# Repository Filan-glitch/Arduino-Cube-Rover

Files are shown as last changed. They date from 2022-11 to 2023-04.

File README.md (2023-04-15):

# Arduino Cube Rover

The Arduino Cube Rover (ACR) is a computer science project made in the university module 'Eingebette Systeme 1' at Hochschule Ruhr West. 
It is about an arduino driving robot controlled by a bluetooth controller with joystick and tilt control. The background is to create a project, that can be reproduced by a school class to get students interested in computer science.

Credits an Arduino Forum System für die Umrechnung der Joystick Rohdaten in Motor Daten. (https://forum.arduino.cc/t/jostick-soll-zwei-motoren-steuern/253709)

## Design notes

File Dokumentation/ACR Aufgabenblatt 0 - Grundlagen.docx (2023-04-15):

Einheit 0: Stromkreis Grundlagen

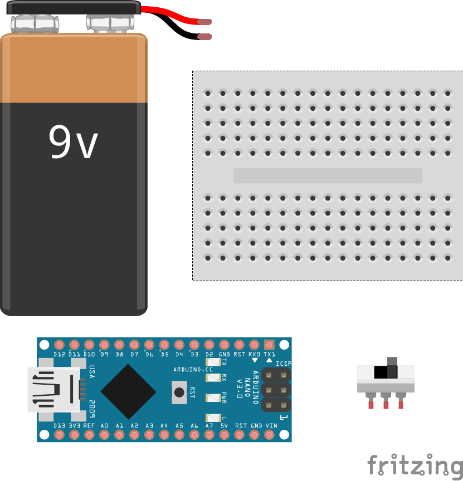
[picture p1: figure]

Materialien

- 1x Arduino Nano
- 1x Breadboard (mittelgroß)
- 1x 9V Batterie
- 1x Batterieblock Kabelaufsatz
- 1x Schalter

Der Arduino wird zum Programmieren immer über ein Kabel an den PC angeschlossen und bekommt dann über den PC den Strom, den es zum Funktionieren braucht. Wenn jedoch ein dynamischer, nicht vom PC abhängiger Roboter und auch Controller gebaut werden soll, muss auf eine kleine mitnehmbare Stromquelle zurückgegriffen werden. In diesem Fall nutzen wir eine 9V Batterie, die direkt an den Arduino angeschlossen werden kann und ihn so mit dem benötigten Strom versorgt.

Abbildung 1 Materialien

Damit der Arduino aber nicht für immer an den Strom angeschlossen ist und einfach die ganze Batterie verbraucht müssen wir eine Steuereinheit verbauen, die den Stromfluss unterbrechen kann und dazu nutzen wir einen Schalter. Dieser kann je nach Auslenkung des Schalters den Stromfluss durchlassen oder blockieren und ist somit perfekt für das An- und Ausschalten des Arduino.

(Falls möglich) Lötvorgang

Wenn man mit verschiedenen Bauteilen arbeitet, kann es häufig dazu kommen, dass man Bauteile nicht mit simplen Jumperkabeln verbinden kann, sondern man selbst Hand anlegen muss und mit dem Lötkolben Bauteile mit Kabeln selbst verlöten muss.

Aufgabe 1

1 | Löte das rote Kabel des Batterieblock Kabelaufsatzes an den mittleren Anschluss des Schalters. Löte ein weiteres rotes Kabel an einen der äußeren Anschlüsse des Schalters.

Das Arbeiten mit Lötkolben ist sehr gefährlich und sollte immer unter höchster Vorsicht durchgeführt werden. Es herrscht Verbrennungsgefahr.

Arduino mit Batterie betreiben

Platziert nun den Arduino Nano mittig auf ein kleines Breadboard, um mit der Verkabelung zu beginnen. Als nächstes müsst ihr den äußeren Anschluss (Pluspol) eures Schalters mit dem VIN-Port des Arduino verbinden, indem ihr das Kabel in einen der Anschlüsse unterhalb des VIN-Ports reinsteckt. Zum Schluss müsst ihr noch das schwarze Kabel vom Batterieblock Kabelaufsatz mit dem GND-Port (Minus Pol) des Arduinos verbinden, dafür steckt ihr das Kabel in ein Loch unterhalb des GND-Ports, der sich neben dem VIN-Port befindet.

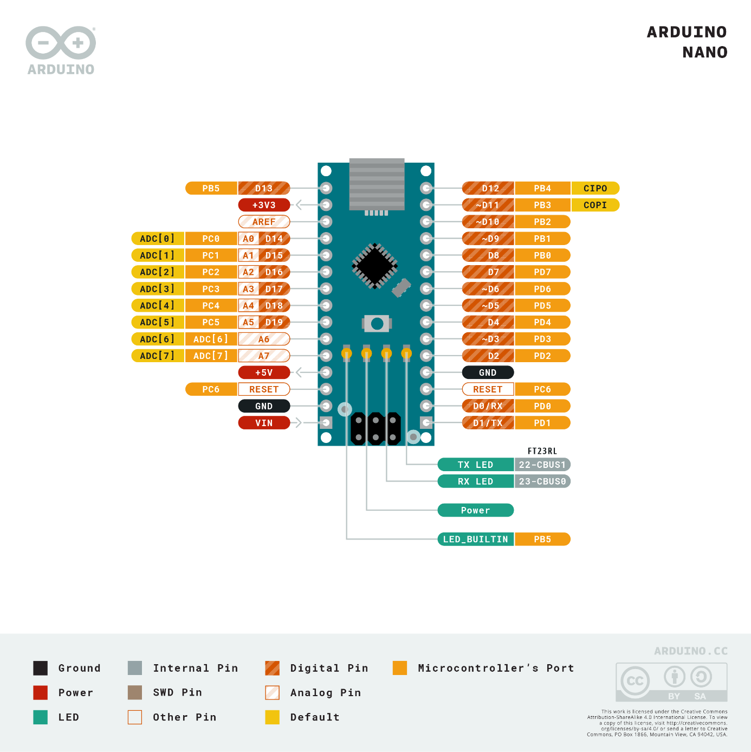
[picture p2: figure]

Abbildung 2 Beschriftung der Anschlüsse des Arduino Nano (https://docs.arduino.cc/hardware/nano)

Aufgabe 2

2 | Baue die beschriebene Schaltung nach, um einen Arduino Nano per Batterie zu betreiben

Bevor der Schalter umgelegt wird, lasse die Schaltung von einer Lehrperson überprüfen. Eine 9V Batterie ist zwar nicht gefährlich aber eine falsche Verkabelung kann schwere Fehler beim Arduino verursachen.

Autoren: Finn Dilan, Felix Neufeld, Jona Tregel Stand: 15.04.2023Seite 1 von 2

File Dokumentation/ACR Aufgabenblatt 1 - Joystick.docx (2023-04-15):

Einheit 1: Joystick

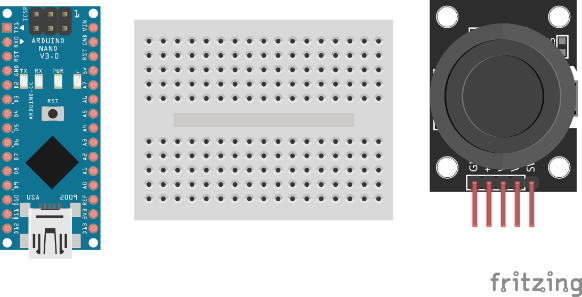
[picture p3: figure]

Materialien

- 1x Arduino Nano mit Verbindungskabel
- 1x mittlere Breadboard
- 1x Joystickmodul
- Jumperkabel weiblich/männlich

Abbildung 1 Materialien

Ein Joystick ist ein Sensor, der die Rotation des Griffs in den zwei Achsen (x-Achse/y-Achse) auslesen kann.

In dieser Einheit wird ein sogenannter analoger Joystick verwendet, welcher die Auslenkung des Griffs mithilfe von zwei Potentiometern ausliest. Ein Potentiometer ist ein elektronisches Bauteil, dass je nach Auslenkung den Widerstand im Stromfluss verändern kann, wird nun dieser Stromfluss ausgelesen kann genau bestimmt werden, wie der Potentiometer ausgerichtet ist. Das vorhandene Joystickmodul hat bereits einen internen Schaltkreis, der den eingehenden und ausgehenden Stromfluss mit den eingebauten Potentiometern verbindet.

Zum Auslesen der Joystick Daten mit dem Arduino müssen wir die Pins des Joystick Moduls nutzen. Wir bilden einen Stromkreis mit den 5V Pins des Arduinos mit dem +5V Pin des Joystickmoduls und dem GND-Pin des Arduinos mit dem GND-Pin des Joystickmoduls. Dadurch fließt nun durch das Joystickmodul Strom. Diesen können wir jedoch noch nicht auslesen, dazu müssen wir die VRx und VRy Pins des Joystickmoduls mit beliebigen Analog Pins des Arduino verbinden. Diese erkennt man an der typischen Kennzeichnung mit einem A und dann einer Zahl, der Pin Nummer, die wir später für die Programmierung brauchen, um auch die richtigen Daten auszulesen.

Joystick anschließen

Der Arduino wird auf dem Breadboard angebracht, um das Verbinden mit Strom und dem Joystick zu vereinfachen.

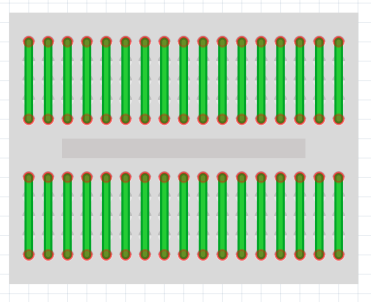
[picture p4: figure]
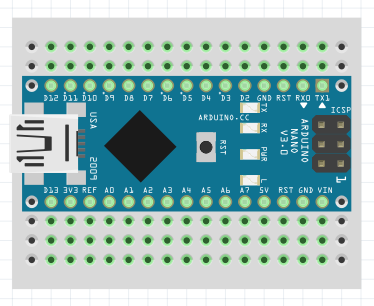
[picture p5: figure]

Abbildung 2 Verbindungen auf dem Breadboard. Jede durchgezogene Linie steht für eine Verbindung der darunter liegenden Anschlüssen.

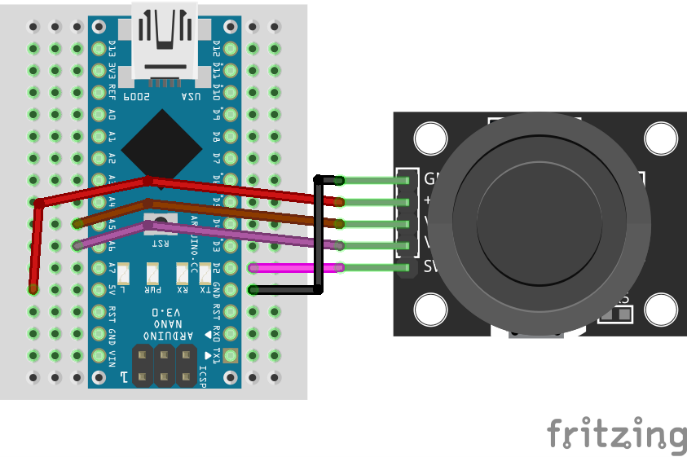
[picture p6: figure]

Die Schaltung des Joysticks ist sehr simpel. Da der Joystick als Modul ein eigenes Leiterbahnensystem besitzt muss nur noch die Anschlüsse des Joysticks mit dem Arduino verbunden werden. Dazu nutzen wir die Informationen aus der Einführung, welche Pins das Modul besitzt und wie sie an den Arduino anzuschließen sind.

Abbildung 3 Schaltbild zum Anschluss eines Joystick Moduls an den Arduino Nano

Wenn nun alles an Ort und Stelle ist wollen wir natürlich auch die Daten des Joysticks auslesen. Der Joystick hat drei Daten-Pins: die horizontale Achse (analog), die vertikale Achse (analog) und den Taster (digital). Digitale Pins müssen zu Beginn eines Skripts immer als Eingang oder Ausgang definiert werden. Dazu nutzt man den Befehl pinMode.

Analoge Pins brauchen diese Definition nicht, weshalb wir direkt mit dem Auslesen der Daten anfangen können. Zum Auslesen benutzen wir den Befehl analogRead.

analogRead(pin);
Beschreibung | Mit diesem Befehl wird der aktuelle Wert an dem angegebenen Pin ausgelesen.
Parameter | pin: Nummer des Pins, dessen Wert ausgelesen werden soll
Rückgabewert | Der ausgelesene Wert als Ganzzahl (int)

Nun könnt ihr die Werte des Joysticks auslesen, wisst jedoch noch nicht, wie man die Werte menschenlesbar anzeigt. Dafür gibt es den seriellen Monitor auf dem man Texte, Werte oder andere nützliche Sachen anzeigen lassen kann. Der Befehl zum Anzeigen von Dingen auf dem seriellen Monitor lautet Serial.print(). Damit die serielle Kommunikation genutzt werden kann, muss in der setup() noch der Befehl Serial.begin() genutzt werden.

Serial.begin(speed);
Beschreibung | Dieser Befehl wird genutzt, um die serielle Kommunikation mit der angegebenen Geschwindigkeit zu starten. Die Geschwindigkeit ist wichtig, damit
Parameter | Speed: Die Geschwindigkeit der Kommunikation (Standard ist 9600, später wird auch 38400 benötigt)
Rückgabewert | void

Serial.print(data); / Serial.println(data);
Beschreibung | Dieser Befehl wird genutzt, um nützliche Informationen auf dem seriellen Monitor anzeigen zu lassen. Serial.println() ist eine Erweiterung von Serial.print(), die nach der angezeigten Information automatisch ein Zeilenumbruch macht.
Parameter | data: Informationen, die auf dem seriellen Monitor angezeigt werden sollen, das kann ein Text sein, eine Variable oder auch Arrays.
Rückgabewert | Gibt die Anzahl an Zeichen zurück, die tatsächlich geschrieben wurden, falls es zu Problemen mit dem Schreiben kommen sollte.

Aufgabe 1

1a | Schließt den Joystick richtig an den Arduino an und erstellt einen kleinen Sketch, mit dem ihr mit Hilfe von Serial.println() die Werte in dem Debug Fenster ausgebt.
1b | Was sind die jeweiligen Wertepaare in den äußersten Ecken des Joysticks? Jeweils in der Form (x-Achse, y-Achse).
| Oben Links
| Oben Rechts
| Unten Links
| Unten Rechts

Mit den Daten arbeiten

Infotext (Große Programmieraufgabe, die map Funktion einführen zum mappen von einem Zahlenbereich auf einen anderen und dann mit mit If-Abfragen, interne LED auf Pin 13 erklären und aufblicken lassen, wenn das produkt der beiden Achsen werte kleiner einem bestimmten Wert ist oder so).

Das Anschließen und Einlesen der Werte haben funktioniert? Dann fangen wir nun an die eingelesenen Werte mal etwas mehr zu benutzen. Die Wertespanne des Joysticks ist, wie sicherlich schon herausgefunden, beschränkt auf Werte von 0 bis 1023. Manchmal ist es jedoch durchaus hilfreich andere Wertespannen zu haben, weil es sich damit leichter arbeiten lässt. Deshalb gibt es den map Befehl.

Aufgabe 2

map(value, fromLow, fromHigh, toLow, toHigh);
Beschreibung | Dieser Befehl arrangiert die Werte so um, dass sie von dem alten Wertebereich nun vollständig in den neuen Wertebereich passen. Dieser Befehl arbeitet nur mit ganzen Zahlen, daher die Grenzen nur als ganze Zahlen angeben.
Parameter | value: die Variable, dessen Werte neu arrangiert werden sollen fromLow: die untere Grenze des alten Wertebereichs fromHigh: die obere Grenze des alten Wertebereichs toLow: die untere Grenze des neuen Wertebereichs toHigh: die obere Grenze des neuen Wertebereichs
Rückgabewert | Die neu arrangierte Ganzzahl mit der dann weitergearbeitet werden kann.

2 | Code schreiben - Lies die x-Werte und y-Werte aus dem Joystick aus und speicher diese in jeweils einer Variable ab - Mappe die Werte, die ursprünglich von 0 bis 1023 gingen auf den neuen Wertebereich von -256 bis 255 - Erstelle eine Bedingung, dass im seriellen Monitor „True“ ausgegeben wird, wenn der x-Wert addiert mit dem y-Wert größer als oder gleich 0 ist. Wenn kleiner, soll „False“ ausgegeben werden.

Den Taster auslesen

Nun beschäftigen wir uns mit dem Taster des Joysticks, der erkennt, ob der Joystick gedrückt wurde. Dazu gibt es den digitalen SW-Pin. Bei digitalen Bauteilen/Anschlüssen müssen wir den Arduino darüber informieren, ob über diesen Pin Daten empfangen oder wir Daten ausgeben wollen. Für diese Definition gibt es den pinMode Befehl.

pinMode(pin, mode);
Beschreibung | Der Befehl legt fest, ob ein bestimmter digitaler Pin als Eingabe oder Ausgabe benutzt werden soll. Wird in void setup() eingesetzt.
Parameter | pin: Nummer des Pins, dessen Modus gesetzt werden soll mode: INPUT (Eingabe) oder OUTPUT (Ausgabe), es gibt auch noch den Spezial Modus INPUT_PULLUP (Eingabe), den wir für den Joystick Taster benötigen werden.
Rückgabewert | void

Wenn wir nun auslesen wollen, ob der Joystick gedrückt wurde, müssen wir den Befehl digitalRead nutzen.

digitalRead(pin);
Beschreibung | Mit diesem Befehl wird an dem angegebenen digitalen Pin ausgelesen, ob der Wert des Pins HIGH oder LOW ist. Der Joystick-Taster gibt immer einen LOW-Wert zurück und wenn gedrückt wechselt er für die Zeit des Drückens auf HIGH
Parameter | pin: Nummer des Pins, dessen Wert ausgelesen werden soll
Rückgabewert | HIGH oder LOW

Das Problem nun ist, dass wir damit nur abfragen können, ob der Taster aktuell gedrückt wird. Wenn gespeichert werden soll, dass der Taster gedrückt wurde, wird es etwas komplizierter. Es muss gespeichert werden, ob der Taster aktuell gedrückt ist (kann auch in der Abfrage direkt ausgelesen werden), es muss gespeichert werden, ob der Taster bei der letzten Abfrage gedrückt war (bool) und es muss einen Modus geben, der hin und her springt, wenn der Taster einmal vollständig gedrückt und losgelassen wurde (enum).

Aufgabe 3

3

Code erweitern

- Lege eine bool Variable an, die speichert, ob der Taster beim letzten Mal gedrückt war.
- Lege einen enum an, der zwei verschiedene Modi definiert.
- Schreibe eine Funktion, die in den jeweils anderen Modus wechselt, wenn die bool Variable auf true ist und der aktuelle Taster LOW ausgelesen wird (nach dem Wechseln nicht vergessen die bool Variable auf false zu setzen). Am Ende der Funktion soll die bool Variable nochmal auf den aktuellen Taster-Wert gesetzt werden.
- Zu guter Letzt soll die Bedingung aus der Aufgabe 2 so geändert werden, dass wenn der erste Modus aktiviert ist, soll weiterhin „True“ ausgegeben werden, wenn xAchse PLUS yAchse größer oder gleich 0 ist, aber wenn der zweite Modus aktiviert ist, soll „True“ ausgegeben werden, wenn xAchse MAL yAchse größer oder gleich 0 ist.

Autoren: Finn Dilan, Felix Neufeld, Jona Tregel Stand: 15.04.2023Seite 1 von 2

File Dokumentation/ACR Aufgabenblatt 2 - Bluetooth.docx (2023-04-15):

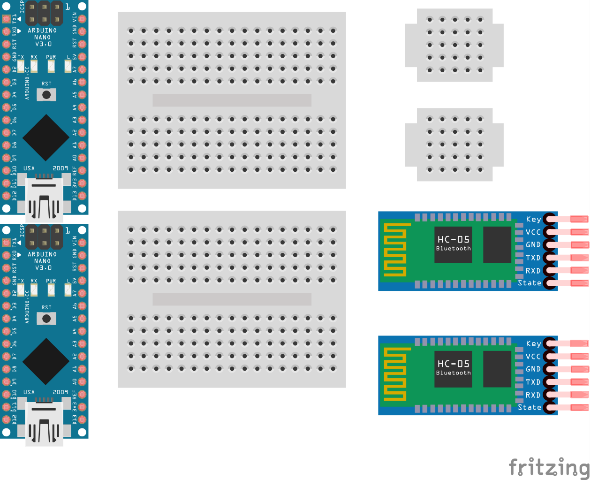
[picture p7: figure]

Einheit 2: Bluetooth Verbindung

Materialien

- 2x Arduino Nano (+Verbindungskabel)
- 2x Bluetooth Modul HC-05
- 2x Breadboards (mittelgroß)
- 2x Breadboards (klein)
- Jumperkabel männlich/männlich und weiblich/männlich

Abbildung 1 Materialien

Im Alltag kommt man ständig mit Bluetooth in Verbindung, aber wie ist das eigentlich technisch umgesetzt? Die grundlegende Kommunikation wird über Bluetooth-Module umgesetzt, Kleine in sich funktionierende Chips, die das Suchen, Verbinden und die Übertragen zu großen Teilen übernehmen und automatisieren.

Es gibt zwei verschiedene Modul Typen, die verschiedene Stellungen übernehmen, denn bei Bluetooth Verbindungen gibt es immer einen Master, der die Verbindung einleitet und die Kommunikation übernimmt und einen Slave, der nur „ausgenutzt“ wird und die Verbindung und Daten annehmen muss. Das HC-06 ist ein reines Slave-Modul, dass keine eigenen Verbindungen aufbauen kann, sondern nur bspw. von einem Handy Daten empfangen kann. Das HC-05 Modul hingegen kann sowohl als Master- als auch Slave-Modul genutzt werden und ist deshalb perfekt für eine Kommunikation in beide Richtungen.

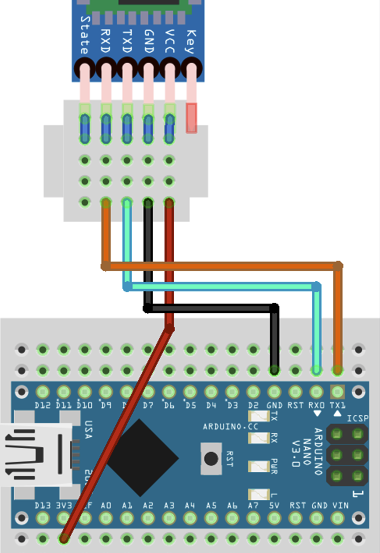
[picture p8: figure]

Das HC-05 Modul besitzt sechs verschiedene Pins: Der GND und VCC-Pin sind für die Stromversorgung zuständig, dabei wird der GND-Pin mit dem GND-Pin des Arduinos verbunden und der VCC-Pin mit dem 3V Pin des Arduino. Der State Pin kann an einen beliebigen Digital Pin angeschlossen werden und gibt ein High/Low-Signal, je nachdem ob aktuell eine aktive Verbindung existiert oder nicht. Der RXD- und TXD-Pin sind die Datenpins des Moduls und werden vertauscht mit den RX0- und TX1- Pin des Arduinos verbunden. Der EN-Pin ist ein Konfigurations-Pin und standardmäßig nicht verbunden.

Bluetooth Modul anschließen

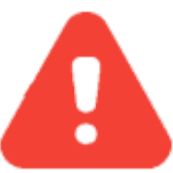
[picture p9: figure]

Der Arduino wird standardmäßig auf dem mittelgroßen Breadboard angebracht. Das HC-05 Modul wird auf dem kleinen Breadboard angebracht, damit das passt, muss man den EN-Pin etwas nach oben biegen.

Unbedingt darauf achten, dass das HC-05 Modul mit dem 3V Pin des Arduinos verbunden wird. Auf keinen Fall an den 5V Pin anschließen. Das kann zu schweren Schäden an dem HC-05 Modul führen.

Aufgabe 1

1 | Befestige den Arduino und das HC-05 Modul auf ihren jeweiligen Breadboards und verbinde die Pins korrekt.

Konfiguration

Das Ziel ist es zwei Arduinos über Bluetooth miteinander kommunizieren zu lassen. Dazu müssen die Bluetooth-Module so konfiguriert werden, dass sie sich finden und automatisch koppeln können. Dabei sollen die Module auch nicht von anderen Geräten gefunden werden können. Um ein HC-05 Modul konfigurieren zu können müssen wir das Modul in den Konfigurationsmodus bringen, dazu verbinden wir den EN-Pin mit dem Arduino an Digital-Pin 3, dann können wir mit dem Skript später den Arduino in den AT-Modus bringen. Dieser Modus lässt sich erkennen daran, dass die LED des HC-05 Moduls anders blinkt als zuvor.

Die Kommunikation des HC-05 Moduls funktioniert über die gleichen Kanäle wie die serielle Kommunikation, daher kann es zu gegenseitigen Störungen kommen. Um das zu verhindern kann man einen virtuellen RX/TX Kanal erstellen. Dazu nutzen wir die Bibliothek „SoftwareSerial“ und können dann mit dem einen neuen seriellen Kanal als Variable definieren, dabei sind dann die beiden angegebenen Pins, die neuen virtuellen RX und TX-Pins. Verbinde also den RX-Pin des HC-05 Moduls jetzt mit Digital-Pin 5 des Arduinos und den TX-Pin des HC-05 Moduls mit dem Digital-Pin 4 des Arduinos. Eine beispielhafte Anwendung siehst du im Skript, dass wir für den Konfigurationsmodus brauchen.

Wenn das Modul sich im AT-Modus befindet, solltest du im seriellen Monitor den Text „Enter AT commands:“ lesen können und wenn du „AT“ eingibst und sendest, sollte ein „OK“ zurückkommen, dann hat alles korrekt funktioniert. Wenn es zu einem Fehler gekommen ist, versuch es noch einmal oder hole dir Hilfe bei deinem Lehrer.

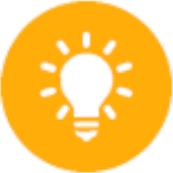
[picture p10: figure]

Es gibt nun ein paar Einstellungen, die im AT-Modus eingestellt werden müssen. Zuerst interessiert uns die Adresse des Moduls, diese kriegen wir mit dem Befehl „AT+ADDR?“, als Antwort sollte dann die Adresse des Moduls erscheinen. Notier dir diese. Danach wollen wir die Rolle des Moduls einstellen. Wir haben zwei Module, eines davon soll als Master eingestellt werden, das andere als Slave. Mit dem Befehl „AT+ROLE=“ kann man die Rolle einstellen, eine 0 an das Ende gehangen ändert die Rolle des Moduls zu einem Slave-Modul, eine 1 an das Ende gehangen ändert die Rolle des Moduls zu einem Master-Modul. Mit dem Befehl „AT+CMODE=0“ können wir dem Modul befehlen, sich mit niemanden zu verbinden, außer der verbundenen Adresse, die wir im nächsten Schritt angeben. Im besten Fall weißt du jetzt die Adressen von beiden Modulen, denn im nächsten Schritt müssen wir beiden Modulen jeweils die Adresse des anderen übergeben. Mit dem Befehl „AT+BIND=“ befehlen wir dem Modul, mit welcher Adresse es sich verbinden soll. Häng einfach die Adresse des anderen Moduls an das Ende des Befehls.

#include <SoftwareSerial.h>//Bibliothek für virtuellen Kanal

SoftwareSerial BTSerial(4, 5); //name(RX-Pin, TX-Pin)

void setup()

{

pinMode(3, OUTPUT);

digitalWrite(3, HIGH);

Serial.begin(38400);

Serial.println("Enter AT commands:");

BTSerial.begin(38400);

}

void loop()

{

if (BTSerial.available()) Serial.write(BTSerial.read());

if (Serial.available()) BTSerial.write(Serial.read());

}

Wenn es beim Hochladen zu Problemen kommt, kann das an dem HC-05 Modul liegt, dass verursacht manchmal Probleme beim Hochladen. Einfach den RX/TX Pin für die Dauer des Hochladen herausziehen, dann sollte alles wieder funktionieren.

Aufgabe 2

2a | Verbinde den EN-Pin und den RX/TX-Pin des HC-05 Moduls an die korrekten Pins des Arduinos.
2b | Lade den oben angegebenen Code auf den Arduino hoch.
2c | Konfiguriere beide deiner HC-05 Module - AT+ADDR? - AT+ROLE=0/1 - AT+CMODE=0 - AT+BIND=ADDR

Verbindung und Kommunikation

Wenn beide HC-05 Module korrekt konfiguriert wurden sollten diese sich nun automatisch verbinden, wenn beide eingeschaltet und kopplungsbereit sind.

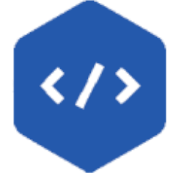
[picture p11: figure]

Wie bereits im Text zu Aufgabe 2 beschrieben, nutzen wir bei der Verwendung von HC-05 Modulen häufig virtuelle serielle Kommunikation. Diese kann effektiv die gleichen Befehle durchführen wie die echte serielle Verbindung (BTSerial.print()/BTSerial.println()). Bei der Kommunikation von rohen Daten über die Bluetooth Verbindung nutzt man eher den Befehl BTSerial.write(). Um die serielle Kommunikation zu nutzen muss sie wieder gestartet werden, diesmal beide Serial.begin() und BTSerial.begin() beide mit der Geschwindigkeit 38400.

BTSerial.write(array, array_length);
Beschreibung | Dieser Befehl wird genutzt, um Rohdaten, die nicht von dem Arduino verändert werden sollen, über die Bluetooth-Verbindung zu verschicken.
Parameter | array: Informationen, die über die Bluetooth-Verbindung geschickt werden sollen, gespeichert in einem Array. Es können nur positive Zahlen geschickt werden, wollen also negative Zahlen übertragen werden, müssen die vorher in positive Zahlen umgewandelt werden und nach der Übertragung wieder zurück. array_length: Die Anzahl an Elementen, die in dem Array enthalten sind
Rückgabewert | Gibt die Anzahl an Zeichen zurück, die tatsächlich geschrieben wurden, falls es zu Problemen mit dem Schreiben kommen sollte.

Der Slave, der die Daten bekommt, will in der loop() nun wissen, ob Daten über die Bluetooth Verbindung angekommen sind und nutzt dafür den BTSerial.available() Befehl.

Für das eigentliche Auslesen der Rohdaten geschieht dann über den BTSerial.readBytes() Befehl.

BTSerial.readBytes(array, array_length);
Beschreibung | Dieser Befehl wird genutzt, um angekommene Rohdaten aus dem Bluetooth-Modul auszulesen.
Parameter | array: Das Array, in das die Daten reingeschrieben werden sollen array_length: Die Anzahl der Elemente die gelesen werden sollen
Rückgabewert | Gibt die Anzahl an Bytes zurück, die tatsächlich gelesen wurden.

BTSerial.available();
Beschreibung | Dieser Befehl wird genutzt, um abzufragen, ob Bluetooth Daten verfügbar sind zu lesen.
Parameter | void
Rückgabewert | Gibt einen bool zurück, true, wenn Daten verfügbar sind, false, wenn nicht

Aufgabe 3

3a | Verbinde beide Arduinos mit ihrem jeweiligen HC-05 Modul.
3b | Code schreiben - Master Sketch - Erstelle einen virtuellen seriellen Kanal - Schicke einmal ein char Array mit den Werten 1, 2 und 3 - Schicke einmal ein char Array mit den Werten -1, 0 und 1 - Gib jeweils alle geschickten Werte auch auf dem seriellen Monitor aus - Slave Sketch - Erstelle einen virtuellen seriellen Kanal - Teste, ob Daten über die Bluetooth-Verbindung angekommen sind - Wenn Daten vorhanden sind, lies sie in ein vorher angelegtes Array ein - Gib die angekommenen Daten auf dem seriellen Monitor aus

Aktuellen Status auslesen

Der letzte Pin, den wir von dem HC-05 Modul bisher noch nicht verwendet haben ist der State-Pin. Dieser Pin kann bei Bluetooth-Verbindungen, die auf eine aktive Verbindung angewiesen sind, ganz hilfreich sein, um zu erkennen, ob die Verbindung noch besteht. Wenn an einen Digital-Pin angeschlossen gibt er dauerthaft HIGH/LOW-Werte, je nach Verbindungsstatus.

Aufgabe 4

4a | Verbinde den State-Pin mit einem Digital-Pin des Arduinos.
4b | Code schreiben - Beide Arduinos sollen auf dem seriellen Monitor „True“ ausgeben, solange eine aktive Bluetooth-Verbindung besteht - Es soll „False“ ausgegeben werden, wenn die Verbindung nicht mehr besteht

Das Modul braucht immer zwischen 3-5 Sekunden bis der State-Pin aktualisiert wird, also bei kleinen Verzögerungen nicht verwirrt sein.

Autoren: Finn Dilan, Felix Neufeld, Jona Tregel Stand: 15.04.2023Seite 1 von 2

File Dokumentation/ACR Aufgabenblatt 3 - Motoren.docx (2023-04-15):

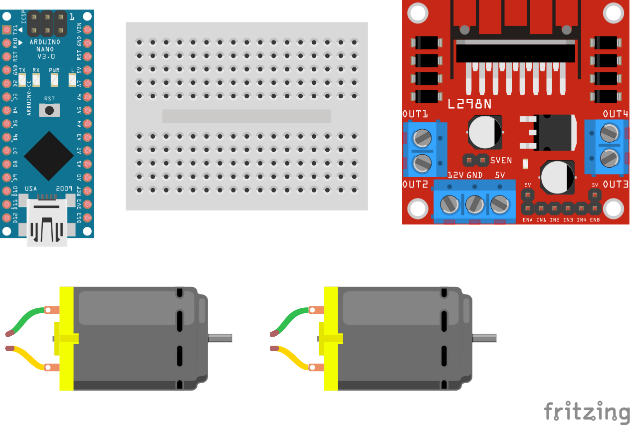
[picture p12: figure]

Einheit 3: Motoren

Materialien

- 1x Arduino Nano
- 2x Gleichstrommotor
- 1x H-Brücke L298N
- 1x Breadboard (mittelgroß)
- Jumperkabel männlich/männlich

Abbildung 1 Materialien

Ein Gleichstrommotor, dient zum Antrieb von vielen verschiedenen Geräten und Modulen. In unserem Fall wird er simpel das Rad antreiben, welches den Roboter fortbewegt. Der Motor besitzt 2 Anschlüsse (+ und –), die für die Stromzufuhr zuständig sind.

Der Motor wird zur korrekten Anwendung an eine sogenannte H-Brücke angeschlossen, diese reguliert durch die vier Schalter (S1, S2, S3, S4) die Stromrichtung und damit die Drehrichtung und auch die Geschwindigkeit des Motors. Des Weiteren besitzt die H-Brücke eine höhere Strombelastbarkeit als der Arduino und ist somit Antriebsstärker, also perfekt für unseren Anwendungszweck.

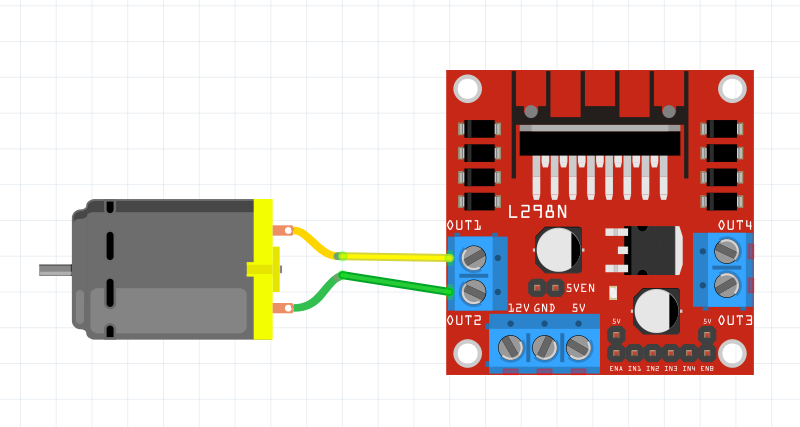
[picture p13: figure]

Die Kabel des Motors, werden an die gleich gekennzeichneten Pins der H-Brücke angeschlossen.

Abbildung 2 Verkabelung Motor/H-Brücke

Die H-Brücke

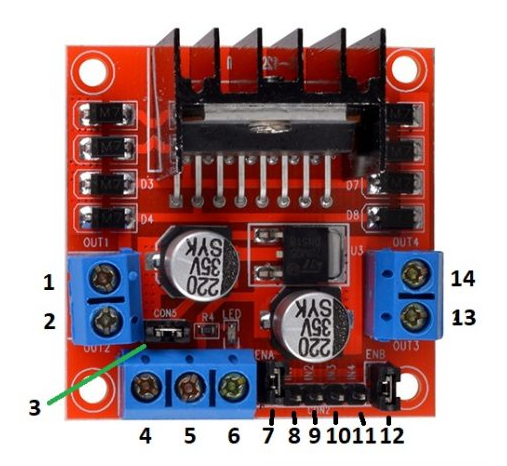
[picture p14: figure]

Damit die Motoren funktionstüchtig an die H-Brücke angeschlossen werden können, muss diese natürlich mit dem Arduino Nano verknüpft sein.

Für eine korrekte Funktionsweise werden im Folgenden die Pins und ihre Funktion angegeben.

Abbildung 3 Pin-out H-Brücke

Nützliche Pins der H-Brücke

Pin | Funktion
1 | Anschluss für den Gleichstrommotor 1 „+“
2 | Anschluss für den Gleichstrommotor 1 „-“
3 | Jumper
4 | Eingang für die Spannungsversorgung der H-Brücke (max. 35V Gleichstrom)
5 | Eingang für den GND
6 | 5V Ausgang, z.B. für die Stromversorgung des Mikrocontrollers
7 | Pin, über den der Gleichstrommotor 1 angesteuert wird. Falls dieser Pin an einem PWM-Pin des Mikrocontrollers angeschlossen wurde, kann die Motorengeschwindigkeit ebenfalls genau bestimmt werden
8 | Pin IN1 – Steuert Gleichstrommotor 1
9 | Pin IN2 – Steuert Gleichstrommotor 1
10 | Pin IN3 – Steuert Gleichstrommotor 2
11 | Pin IN4 – Steuert Gleichstrommotor 2
12 | Pin, über den der Gleichstrommotor 2 angesteuert wird. Falls dieser Pin an einem PWM-Pin des Mikrocontrollers angeschlossen wurde, kann die Motorengeschwindigkeit ebenfalls genau bestimmt werden
13 | Anschluss für den Gleichstrommotor 2 „+“
14 | Anschluss für den Gleichstrommotor 2 „-“

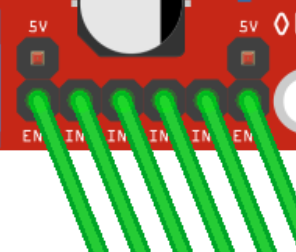
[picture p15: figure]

Nutze zuerst 6 Kabel und stecke jeweils einen Kopf in die Pins 7-12 der H-Brücke (siehe „Die H-Brücke“).

Die anderen Enden der Kabel werden, ohne sich zu überkreuzen an die Pins des Arduinos D11-D6 gesteckt.

Abbildung 4 Verkabelung Digital Anschlüsse

Aufgabe 1

Die Motoren sollen beim Testen der Funktionen die Rotationsrichtung, sowie die Geschwindigkeit ändern können! Pins, beachten.

1 | Platziere den Arduino wie bekannt auf dem Breadboard und schließe dann die H-Brücke an den Arduino an. Beachte die Pins 7 und 12 an PWM-Pins des Arduinos anzuschließen.

Motoren an die H-Brücke anschließen

Wir nehmen die Pins 1,2 und 13,14 für die Kabel der Motoren.

Beachte,

dass die mit „+“ und „-“ gekennzeichneten Pins der H-Brücke mit den gleichnamigen Kabeln der Motoren verbunden werden und der „+“ Pin auf der einen Seite oben und der „-“Pin auf der anderen oben ist!

Da die die Motoren eine höhere Spannung benötigen als der Arduino geben kann, benötigt die H-Brücke eine zusätzliche Spannungsquelle. Also schließen wir an die vorgesehenen Pins (Eingang, GND) der H-Brücke eine 9V Batterie an.

Aufgabe 2

2 | Verbinde die Motoren mit den richtigen Pins der H-Brücke. Schließe eine 9V Batterie an die H-Brücke als zusätzliche Spannungsquelle an.

Motoren initialisieren

Die Motoren werden über die zwischengeschaltete H-Brücke angesteuert und besitzen dafür drei Anschlüsse. Den Geschwindigkeits-Anschluss und jeweils zwei Richtungs-Anschlüsse. Da das Merken der Pin-Nummern und ständige schreiben der Zahlen schnell zu Fehlern kommen kann, speichern wir die Pin-Nummern von Modulen ab sofort als Variablen ab. Der Effizienz wegen werden die Variablen als const deklariert. Der Datentyp ist ein int.

Da bei den Motoren sämtliche Anschlüsse digital sind, müssen wir alle sechs Pins in der setup() als OUTPUT definieren.

Aufgabe 3

3 | Code schreiben - Erstelle konstante Variablen, die die Pin-Nummern abspeichern. Überlege dir eine gute Bezeichnung, damit der Code einfacher zu lesen ist. - Definiere alle Anschlüsse in der setup() als OUTPUTS

Motoren ansteuern

Damit die Motoren angesteuert werden können, müssen wir sowohl die Geschwindigkeit als auch die Richtung angeben. Die Geschwindigkeit geben wir an, indem wir dem Geschwindigkeits-Pin mit dem neuen Befehl analogWrite() eine Geschwindigkeit vorgeben, dabei ist 0 Stillstand und 255 Vollgas. Die Richtung bestimmen wir über die zwei Richtungs-Pins. Diese müssen auf gegensätzliche HIGH/LOW Werte gesetzt werden. Also Richtungs-Pin 1 wird auf HIGH gesetzt und Richtungs-Pin 2 auf LOW ist vorwärts, während andersherum rückwärtsfahren bedeutet. Wenn beide Pins auf LOW gesetzt werden, ist das der Stillstand Modus und der Motor hört auf sich zu drehen. Dazu nutzen wir den neuen Befehl digitalWrite(). Ein dritter nützlicher Befehl ist der Warte-Befehl delay(). Damit kann man das Programm für kurze Zeit pausieren

delay(int);
Beschreibung | Mit diesem Befehl kann man die Ausführung des nachfolgenden Codes für die angegebene Zeit pausieren. Gesendete Signale bleiben aktiv.
Parameter | int: Die Anzahl an Millisekunden, die das Programm pausiert werden soll (1000ms = 1s)

digitalWrite(pin, HIGH/LOW);
Beschreibung | Mit diesem Befehl kann man auf dem angegebenen Pin digitale Signale (HIGH oder LOW) senden.
Parameter | pin: Nummer des Pins, auf der das Signal gesendet werden soll HIGH/LOW: die Auswahl des Signals, das gesendet werden soll, entweder ein HIGH oder ein LOW-Signal.
Rückgabewert | void

analogWrite(pin, int);
Beschreibung | Mit diesem Befehl kann man auf dem angegebenen Pin analoge Signale (0-255) senden.
Parameter | pin: Nummer des Pins, auf der das Signal gesendet werden soll int: Die Ganzzahl, die als Signal gesendet werden soll, bei Nutzung von Variablen, muss der Datentyp int sein.
Rückgabewert | void

Aufgabe 4

4 | Code erweitern - Definiere eine enum, die die Richtung abspeichern kann (vorwärts, rückwärts oder stillstand). - Erstelle zwei Hilfsfunktionen, eine jeweils für jeden Motor, die eine Richtung übergeben bekommt und die jeweiligen Richtungs-Pin korrekt ansteuert. - Lass den ersten Motor vorwärts rotieren mit der Geschwindigkeit von 200 für zwei Sekunden rotieren. - Lass danach den zweiten Motor zwei Sekunden rückwärts rotieren mit einer Geschwindigkeit von 150. - Versetze beide Motoren in Stillstand für zwei Sekunden (es reicht die Richtungs-Pins auf Stillstand zu stellen).

Autoren: Finn Dilan, Felix Neufeld, Jona Tregel Stand: 15.04.2023Seite 1 von 2

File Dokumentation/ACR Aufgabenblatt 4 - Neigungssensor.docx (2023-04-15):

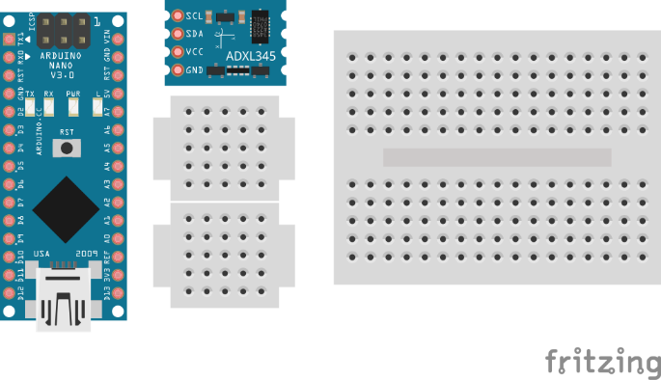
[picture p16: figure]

Einheit 4: Neigungssensor

Materialien

- 1x Neigungssensor (ADXL345)
- 1x Arduino Nano
- 1x Breadboards (mittelgroß)
- 2x Breadboards (klein)
- Jumper Kabel männlich/männlich

Abbildung 1 Materialien

Mit dem Neigungssensor ist es möglich die Informationen zur Lage und Beschleunigung des Sensors auszulesen. Dadurch ist es beispielsweise möglich Bewegungssteuerung in Controllern umsetzen. Der Neigungssensor wird mit dem Arduino Nano durch die I²C-Kommunikationstechnologie verbunden.

Der Neigungssensor misst drei Werte, um zu zeigen, wie er in X-, Y- und Z-Richtung ausgerichtet ist. Diese Werte können zwischen -256 und 255 liegen, abhängig davon, wie der Sensor ausgerichtet ist.

Um den Neigungssensor mit dem Arduino Nano zu verbinden, benötigen wir vier Kabel. Zuerst verbinden wir GND am Neigungssensor mit GND am Arduino, und 5V am Neigungssensor mit dem 5V-Output des Arduinos. Für die SCL- und SDA-Leitung am Arduino benötigen wir die analogen Pins A5 und A4, wobei A5 die SCL-Leitung und A4 die SDA-Leitung ist. Also verbinden wir den SCL des Neigungssensors mit A5 und SDA mit A4.

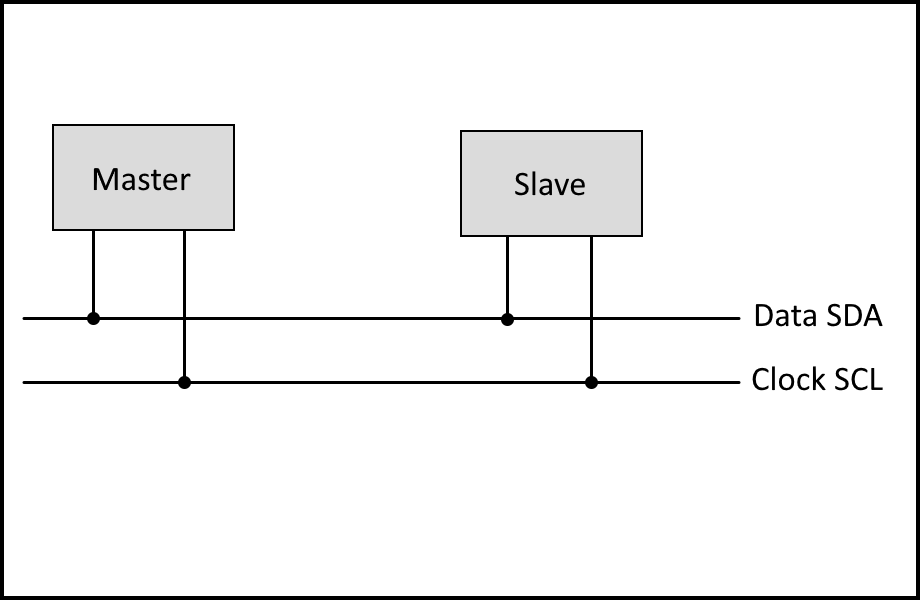
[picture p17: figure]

I²C (Inter integrated circuit)

I²C ist eine Art von Kommunikation zwischen elektrischen Geräten, die zwei Leitungen hat: die SDA-Leitung (Serial Data) und die SCL-Leitung (Serial Clock). Diese sind für die Datenübertragung und Synchronisation verantwortlich. Es gibt auch ein Master-Modul und mehrere Slave-Module mit eindeutigen Nummern. In unserem Fall ist der Master der Arduino Nano und der Slave der Neigungssensor. Der Master und alle Slaves müssen mit der SCL- und SDA-Leitung verbunden sein (siehe Abbildung). Da wir nur einen Slave haben, können wir ihn direkt mit dem Master verbinden und benötigen keine Zwischenleitung.

Abbildung 2 I²C Master-Slave Illustration

Aufgabe 1

1 | Zeichne Abbildung 2 mit einem weiteren Slave-Modul

Neigungssensor anschließen

Wir nehmen uns ein mittelgroßes Breadboard und platzieren den Arduino Nano darauf. Auch den Neigungssensor platzieren wir auf zwei kleine Breadboards, mit jeweils den Pins auf einem der kleinen Breadboards. Jetzt brauchen wir vier männlich/männlich Kabel für die Verbindung. Zuerst verbinden wir GND vom Arduino mit GND vom Neigungssensor und 5V mit 5V. Der SDA-Anschluss beim Arduino ist der Analoge Port 4, also verbinden wir A4 mit SDA, um Daten zu übertragen. Schließlich müssen wir den Analogen Port 5, welcher der SCL-Anschluss beim Arduino ist, mit SCL vom Neigungssensor verbinden, um die Kommunikation zu synchronisieren.


Aufgabe 2

2 | Baue die beschriebene Schaltung nach und lasse sie vom Lehrer überprüfen

Achtung überprüfen lassen

Verbindet eure Schaltung noch nicht mit einer Energiequelle, bevor euer Lehrer nicht eure Schaltung überprüft hat. Bei falscher Schaltung kann es zur Beschädigung von Bauteilen kommen.

Neigungssensor anlegen

Jetzt wo wir den Neigungssensor richtig verkabelt haben, müssen wir noch die Kommunikation einrichten und die Daten auslesen. Zuerst einmal brauchen wir die Bibliotheken ADXL345.h und Wire.h. Die Wire.h Bibliothek kann direkt eingebunden werden, die ADXL345.h muss vorher aus dem Bibliothekmanager installiert werden. Einfach in dem Bibliothekmanager nach ADXL345 suchen, da sollten einige verschiedene Bibliotheken erscheinen. Wir wählen die Bibliothek „Accelerometer ADXL345“ von Seeed Studio. Zu Beginn müssen wir uns eine Variable des Typen ADXL345 anlegen.

#include <Wire.h>

Beschreibung | Fügt dem Sketch die Wire Bibliothek hinzu, welche benötigt wird, um Daten per I²C zu empfangen und zu senden.

#include <ADXL345.h>

Beschreibung | Fügt dem Sketch die ADXL345 Bibliothek hinzu, um den Neigungssensor benutzen zu können.

ADXL345 bezeichner;
Beschreibung | Legt eine Variable vom Typen ADXL345 an, mit der wir arbeiten können. Der Bezeichner kann frei gewählt werden sollte aber geeignet gewählt werden

Aufgabe 3

3 | Code schreiben - Binde die Bibliothek Wire.h ein - Binde die Bibliothek ADXL345.h ein - Erstelle eine Variable des Typen ADXL345 mit geeigneter Bezeichnung

Sensordaten auslesen

Jetzt müssen wir noch die Daten aus dem Neigungssensor auslesen. Dafür müssen wir zunächst den Sensor starten mit powerOn.

adxl.powerOn();
Beschreibung | Startet euren Neigungssensor. Die Funktion müsst ihr über die Variable des Typen ADXL345 aufrufen.
Parameter | void
Rückgabewert | void

Zum Auslesen der tatsächlichen Daten aus dem Neigungssensor gibt es den Befehl adxl.readXYZ(), der direkt alle drei Neigungen ausliest.


Aufgabe 4

adxl.readXYZ(&x, &y, &z);
Beschreibung | Mit diesem Befehl kann man die Neigung aller drei Achsen des Sensors auslesen und direkt in angegebene Variablen abspeichern.
Parameter | &x: Die Variable, in die der Neigungswert der x-Achse gespeichert werden soll (das &-Zeichen muss bleiben), der Datentyp ist int &y: Die Variable, in die der Neigungswert der y-Achse gespeichert werden soll &z: Die Variable, in die der Neigungswert der z-Achse gespeichert werden soll (das &-Zeichen muss bleiben)
Rückgabewert | void

4a | Code schreiben - Starte den Neigungssensor in der Setup Funktion - Speichere die Neigungs Werte in Variablen ab - Gib die Werte schön formatiert mit einem kleinen Delay auf dem seriellen Monitor wieder
4b | Teste aus, wie du den Neigungssensor Bewegen musst, um einen positiven und negativen Wert auf der X-Achse zu bekommen, ohne dass die anderen Werte sich verändern.

Bei Fragen bezüglich der ADXL345 Bibliothek oder bei Interesse an dem Source Code der Bibliothek einfach auf der GitHub Seite vorbeischauen: https://github.com/Seeed-Studio/Accelerometer_ADXL345

Autoren: Finn Dilan, Felix Neufeld, Jona Tregel Stand: 15.04.2023Seite 1 von 2

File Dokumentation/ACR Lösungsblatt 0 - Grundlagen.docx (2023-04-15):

Einheit 0: Stromkreis Grundlagen

In dieser Einheit geht es um die grundlegende Stromzufuhr und den Bau von Stromkreisen, sodass es bei späteren Verkabelungen von Bauteilen nicht zu Schäden kommt.

Inhalt der Einheit: | Stromkreise bauen und verstehen
Dauer der Einheit: | Weniger als eine Schulstunde (20-30 min) Mit Löten tendenziell eine ganze Schulstunde (45-60 min)
Zielgruppe: | Ab Klasse 9
Methodik: | Partnerarbeit präferiert, je nach Ausstattung
Vorkenntnisse: | Lötkenntnisse (nicht zwingend erforderlich), Benutzung von Breadboards, simples Verständnis von Strom(-kreisen)

Benötigte Materialien: | - Arbeitsblatt Stromkreis Grundlagen - Lötkolben und Zubehör
| - 1x Arduino Nano - 1x Breadboard (mittelgroß) - 1x 9V Batterie - 1x Batterieblock Kabelaufsatz - 1x Schalter

Lernziele: | - Kompetenzen - Mit externen Stromzufuhr umgehen lernen - Tendenziell Löten verbessern - Befehle: - Keine

Musterlösungen zu den Aufgaben

Aufgabe 1

1 | Löte das rote Kabel des Batterieblock Kabelaufsatzes an ein äußeren Anschluss des Schalters. Löte ein weiteres rotes Kabel an den mittleren Anschluss des Schalters.
| Normaler Lötvorgang. Es sollte darauf geachtet werden, dass sich das Lötzinn der beiden Anschlüsse am Schalter nicht berühren, im besten Fall sogar isolieren, ansonsten wird der Schalter überbrückt und hat keinen Effekt.

Aufgabe 2

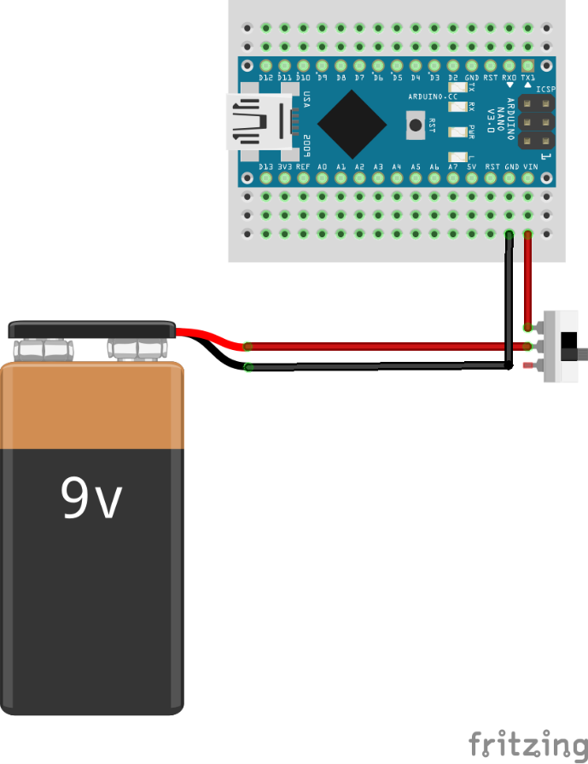
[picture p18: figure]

2 | Baue die beschriebene Schaltung nach, um einen Arduino Nano per Batterie zu betreiben

Autoren: Finn Dilan, Felix Neufeld, Jona Tregel Stand: 11.04.2023Seite 1 von 2

Infos für Lehrkräfte und Musterlösungen

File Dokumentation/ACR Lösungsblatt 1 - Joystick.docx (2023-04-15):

Einheit 1: Joystick

In dieser Einheit geht es um die Verwendung eines Joystick Moduls und das Verständnis der Wirkungsweise eines Joysticks. Aufbauend darauf werden nützliche Techniken im Umgang mit dem Joystick vermittelt.

Inhalt der Einheit: | Joystick auslesen und Daten verarbeiten
Dauer der Einheit: | 1-2 Schulstunde (ca. 60 min)
Zielgruppe: | Ab Klasse 9
Methodik: | Partnerarbeit präferiert, je nach Ausstattung
Vorkenntnisse: | Grundkenntnisse Programmierung (Variablen, Schleifen, Bedingter Code, Funktionen, Enums), Unterschiede digital/analog, Umgang mit Arduino IDE, void setup/void loop, vorheriges Arbeitsblatt

Benötigte Materialien: | - Computer mit vorinstallierter Arduino Umgebung - Arbeitsblatt Joystick
| - 1x Arduino nano (+ Verbindungskabel) - 1x Mittleres Breadboard - 1x Joystickmodul - Jumperkabel weiblich/männlich

Lernziele: | - Kompetenzen - Schaltkreise bauen - Digitale und Analoge Daten auslesen - Befehle: - pinMode - digitalRead - analogRead - Serial.begin() - Serial.print()/Serial.println() - map

Musterlösungen zu den Aufgaben

Aufgabe 1

1a | Schließt den Joystick richtig an den Arduino an und gebt die Werte in dem Debug Fenster aus.
| Schaltbild siehe Abbildung 3 Aufgabenzettel
1b | Was sind die jeweiligen Wertepaare in den äußersten Ecken des Joysticks? Jeweils in der Form (x-Achse, y-Achse).
| Oben Links | (0, 0)
| Oben Rechts | (1023, 0)
| Unten Links | (0, 1023)
| Unten Rechts | (1023, 1023)

Aufgabe 2

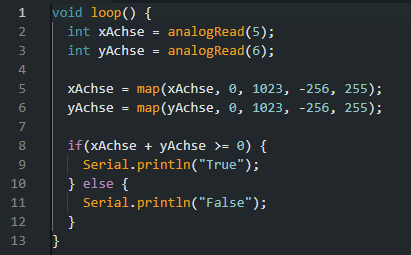
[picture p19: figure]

2 | Schreibe einen Sketch, der die x-Werte und y-Werte aus dem Joystick ausliest und in jeweils einer Variable speichert, die Werte dann von den ursprünglichen 0 bis 1023 auf -256 bis 255 mappt und dann abfragt, ob x-Wert PLUS y-Wert größer oder gleich 0 ist. Ist es größer wird im seriellen Monitor „True“ ausgegeben, ansonsten „False“

Aufgabe 3

3

Erweitere deinen Sketch aus Aufgabe 2, um folgende Dinge. Lege eine bool Variable an, die speichert, ob der Taster beim letzten Mal gedrückt war. Lege einen enum an, der zwei verschiedene Modi definiert. Schreibe eine Funktion, die in den jeweils anderen Modus wechselt, wenn die bool Variable auf true ist und der aktuelle Taster LOW ausgelesen wird (nach dem Wechseln nicht vergessen die bool Variable auf false zu setzen). Am Ende der Funktion soll die bool Variable nochmal auf den aktuellen Taster-Wert gesetzt werden. Zu guter Letzt soll die Bedingung aus der Aufgabe 2 so geändert werden, dass wenn der erste Modus aktiviert ist, soll weiterhin „True“ ausgegeben werden, wenn xAchse PLUS yAchse größer oder gleich 0 ist, aber wenn der zweite Modus aktiviert ist, soll „True“ ausgegeben werden, wenn xAchse MAL yAchse größer oder gleich 0 ist.

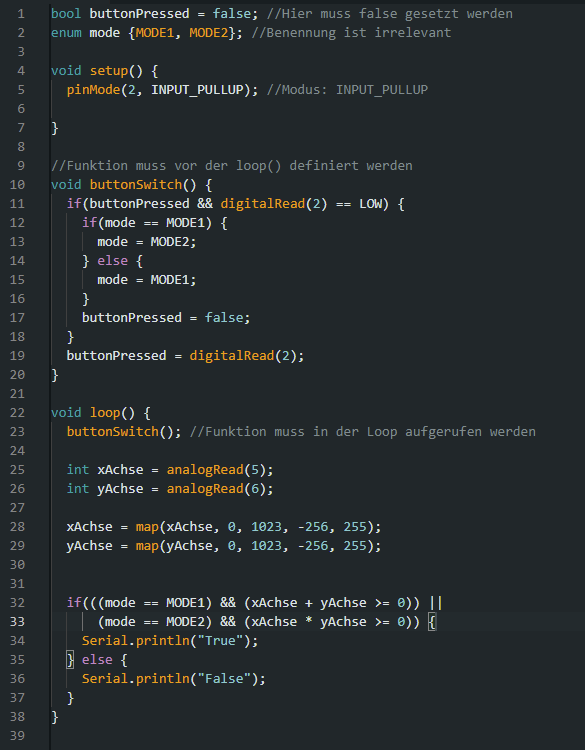
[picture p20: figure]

Autoren: Finn Dilan, Felix Neufeld, Jona Tregel Stand: 11.04.2023Seite 1 von 2

Infos für Lehrkräfte und Musterlösungen

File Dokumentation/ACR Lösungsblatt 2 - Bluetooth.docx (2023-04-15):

Einheit 2: Bluetooth Verbindung

In dieser Einheit wird die drahtlose Kommunikationsmethode Bluetooth näher unter die Lupe genommen. Die Schüler kommen in Kontakt mit einem Bluetooth-Modul, konfigurieren ihn so wie gebraucht und senden dann Daten zwischen zwei Modulen.

Inhalt der Einheit: | Konfiguration und Nutzung von HC-05 Bluetooth Modulen
Dauer der Einheit: | 2-3 Schulstunden (ca. 90 min)
Zielgruppe: | Ab Klasse 9
Methodik: | Mind. Partnerarbeit erforderlich, größere Gruppen möglich
Vorkenntnisse: | Sämtliche vorherige Aufgabenblätter, Funktionsweise von Arrays

Benötigte Materialien: | - 2x Computer mit vorinstallierter Arduino Umgebung - Arbeitsblatt Bluetooth Verbindung
| - 2x Arduino Nano (+ Verbindungskabel) - 2x Breadboard (mittelgroß) - 2x Breadboard (klein) - 2x HC-05 Bluetooth Modul - Jumperkabel männlich/männlich und weiblich/männlich

Lernziele: | - Kompetenzen - Funktionsweise von Bluetooth-Kommunikation - Konfiguration von Bluetooth-Modulen - Übertragungsmethoden von unübertragbaren Daten - Befehle: - AT-Befehle - BTSerial.write() - BTSerial.available() - BTSerial.readBytes()

Musterlösungen zu den Aufgaben

Aufgabe 1

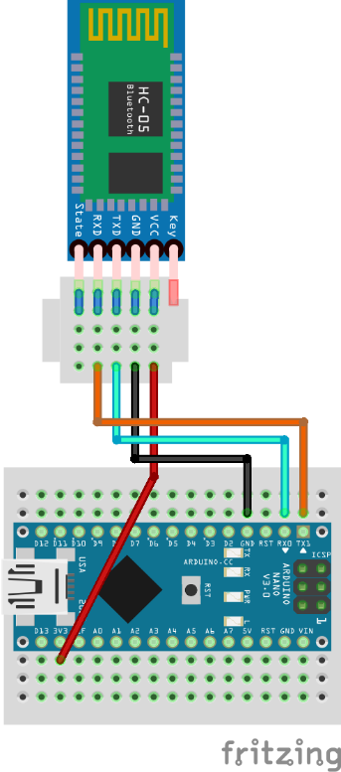
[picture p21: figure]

1 | Befestige den Arduino und das HC-05 Modul auf ihren jeweiligen Breadboards und verbinde die Pins korrekt.

Aufgabe 2

2a | Verbinde den EN-Pin und den RX/TX-Pin des HC-05 Moduls an die korrekten Pins des Arduinos.

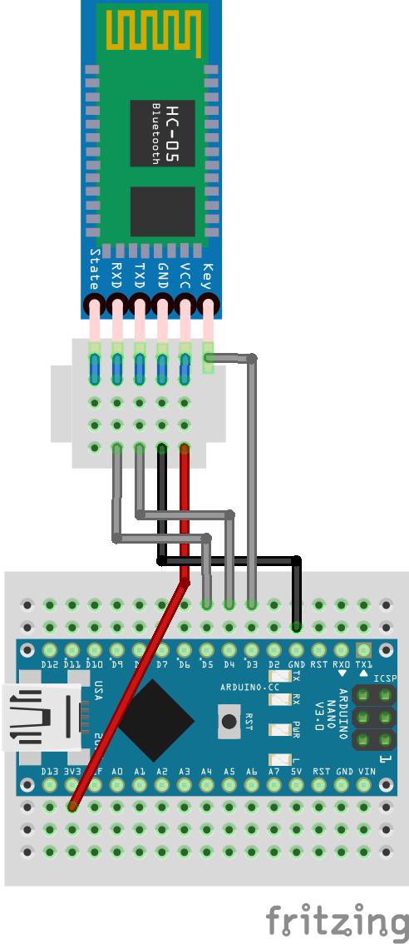
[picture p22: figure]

2b | Lade den oben angegebenen Code auf den Arduino hoch.
| Darauf achten, dass HC-05 auszustecken, weil es sonst zu Upload-Problemen kommt.
2c | Konfiguriere beide deiner HC-05 Module - AT+ADDR? - AT+ROLE=0/1 - AT+CMODE=0 - AT+BIND=ADDR

Aufgabe 3

3a | Verbinde beide Arduinos mit ihrem jeweiligen HC-05 Modul.

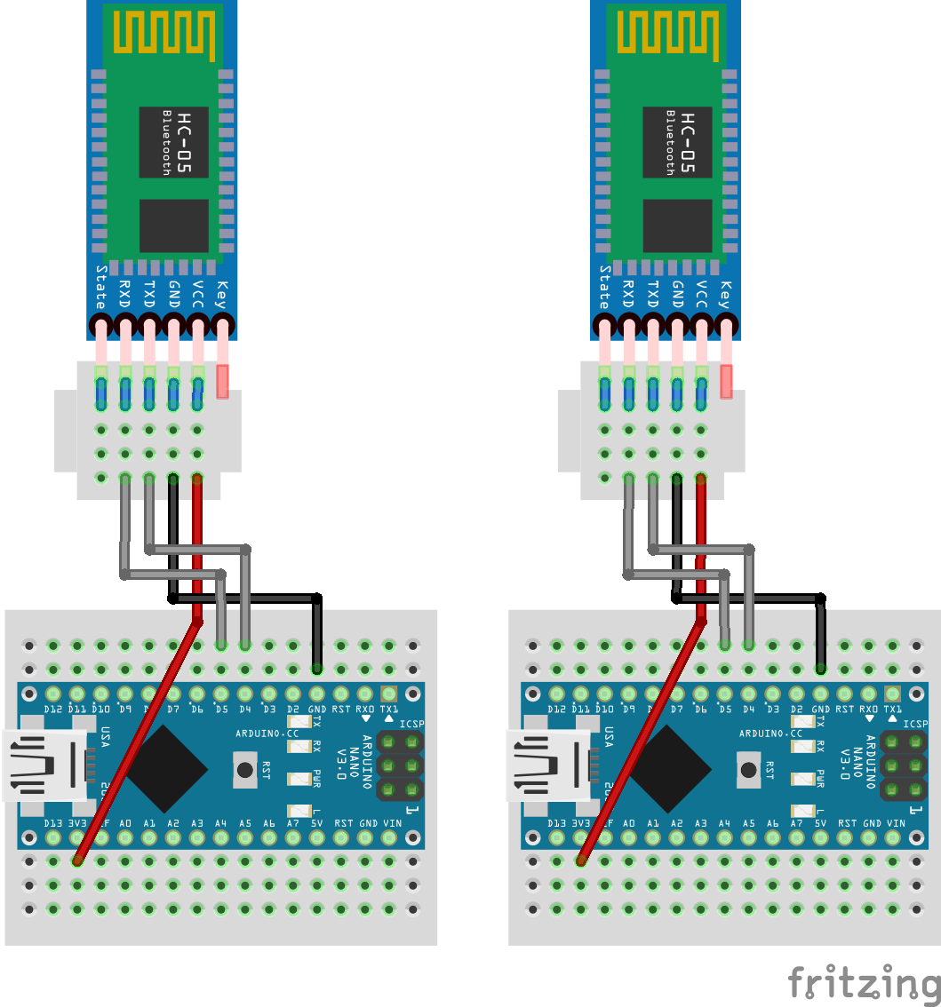
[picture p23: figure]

3b | Code schreiben - Master Sketch - Erstelle einen virtuellen seriellen Kanal - Schicke einmal ein char Array mit den Werten 1, 2 und 3 - Schicke einmal ein char Array mit den Werten -1, 0 und 1 - Slave Sketch - Erstelle einen virtuellen seriellen Kanal - Teste, ob Daten über die Bluetooth-Verbindung angekommen sind - Wenn Daten vorhanden sind, lies sie in ein vorher angelegtes Array ein - Gib die angekommenen Daten auf dem seriellen Monitor aus

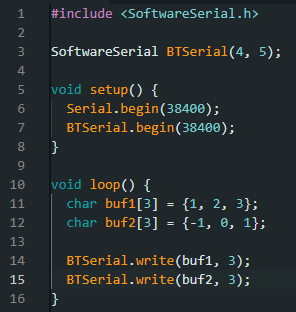
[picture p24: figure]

| Master: Slave:

Aufgabe 4


4a | Verbinde den State-Pin mit einem Digital-Pin des Arduinos.
| Wie in Aufgabe 3 nur mit dem State-Pin an einen D-Pin angeschlossen.
4b | Code schreiben - Beide Arduinos sollen auf dem seriellen Monitor „True“ ausgeben, solange eine aktive Bluetooth-Verbindung besteht - Es soll „False“ ausgegeben werden, wenn die Verbindung nicht mehr besteht

Autoren: Finn Dilan, Felix Neufeld, Jona Tregel Stand: 11.04.2023Seite 1 von 2

Infos für Lehrkräfte und Musterlösungen

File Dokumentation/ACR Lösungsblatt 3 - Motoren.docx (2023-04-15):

Einheit: Motoren

In dieser Einheit geht es um die Verwendung von Gleichstrommotoren und die Wirkungsweise einer H-Brücke als Verbindungsstück zwischen Motor und Arduino zur Stromversorgung, sowieso Steuerung von Richtung und Geschwindigkeit.

Inhalt der Einheit: | Erste Anwendung der H-Brücke und Ansteuerung der Motoren
Dauer der Einheit: | 1-2 Schulstunden (ca. 60 min)
Zielgruppe: | Ab Klasse 9
Methodik: | Partnerarbeit präferiert, je nach Ausstattung
Vorkenntnisse: | Wie baut man einen simplen Stromkreis auf, analoge/digitale Pins, ein Sketch erstellen und hochladen, void Setup/void loop, Deklaration von Variablen, Benutzung des Breadboards

Benötigte Materialien: | - Computer mit vorinstallierter Arduino Umgebung - Arbeitsblatt Motoren
| - Arduino Nano (+Verbindungskabel) - 2x Gleichstrommotoren - 1x H-Brücke L298N - 1x Breadboard (mittelgroß) - Jumperkabel männlich/männlich - Schraubenzieher

Lernziele: | - Kompetenzen: - Stromversorgung der H-Brücke - Benutzung der H-Brücke - Ansteuern der Motoren - Befehle: - digitalWrite - analogWrite - delay

Musterlösungen zu den Aufgaben

Aufgabe 1


1 | Platziere den Arduino wie bekannt auf dem Breadboard und schließe dann die H-Brücke an den Arduino an. Beachte die Pins 7 und 12 an PWM-Pins des Arduinos anzuschließen.

Aufgabe 2


2 | Verbinde die Motoren mit den richtigen Pins der H-Brücke. Schließe eine 9V Batterie an die H-Brücke als zusätzliche Spannungsquelle an.

Aufgabe 3


3 | Code schreiben - Erstelle konstante Variablen, die die Pin-Nummern abspeichern. Überlege dir eine gute Bezeichnung, damit der Code einfacher zu lesen ist. - Definiere alle Anschlüsse in der setup() als OUTPUTS

Aufgabe 4

4

Code erweitern

- Definiere eine enum, die die Richtung abspeichern kann (vorwärts, rückwärts oder stillstand).
- Erstelle zwei Hilfsfunktionen, eine jeweils für jeden Motor, die eine Richtung übergeben bekommt und die jeweiligen Richtungs-Pin korrekt ansteuert.
- Lass den ersten Motor vorwärts rotieren mit der Geschwindigkeit von 200 für zwei Sekunden rotieren.
- Lass danach den zweiten Motor zwei Sekunden rückwärts rotieren mit einer Geschwindigkeit von 150.
- Versetze beide Motoren in Stillstand für zwei Sekunden (es reicht die Richtungs-Pins auf Stillstand zu stellen).

Wiederhole den Vorgang mit umgedrehten Drehrichtungen.


Autoren: Finn Dilan, Felix Neufeld, Jona Tregel Stand: 11.04.2023Seite 1 von 2

Infos für Lehrkräfte und Musterlösungen

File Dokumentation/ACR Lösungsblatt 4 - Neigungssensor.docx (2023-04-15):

Einheit 4: Neigungssensor

In dieser Einheit wird die Erkennung von Neigungen mit Hilfe eines Neigungssensor behandelt. Dabei wird die Kommunikationsmethode I²C eingeführt und näher erläutert.

Inhalt der Einheit: | Nutzung des Neigungssensors, sowie eine kleine Einführung in I²C
Dauer der Einheit: | 1 bis 2 Schulstunden (ca. 60 min)
Zielgruppe: | Ab Klasse 9
Methodik: | Partnerarbeit präferiert, je nach Ausstattung
Vorkenntnisse: | Sämtliche Vorkenntnisse aus vorherigen Arbeitsblättern, Installieren und Einbinden von externen Bibliotheken

Benötigte Materialien: | - Computer mit vorinstallierter Arduino Umgebung - Arbeitsblatt Neigungssensor
| - 1x Arduino Nano (+ Verbindungskabel) - 1x Breadboard (mittelgroß) - 2x Breadboard (klein) - 1x Neigungssensor (ADXL345) - Jumperkabel männlich/männlich

Lernziele: | - Kompetenzen: - Basiswissen zu I²C - Aufsetzen eines Neigungssensors - Ansteuerung und auslesen eines Neigungssensors - Mappen der erhaltenen Werte - Befehle: - powerOn - readXYZ

Musterlösungen zu den Aufgaben

Aufgabe 1


1 | Zeichne Abbildung 2 mit einem weiteren Slave-Modul

Aufgabe 2

2 | Baue die beschriebene Schaltung nach und lasse sie vom Lehrer überprüfen


| Neigungssensor Bauteil nicht ganz akkurat. Normalerweise Anschlüsse auf beiden Seiten des Moduls. Stromanschlüsse auf der einen Seite und SDA/SCL auf der anderen, daher zwei kleine Breadboards.

Aufgabe 3


2 | Code schreiben - Binde die Bibliothek Wire.h ein - Binde die Bibliothek ADXL345.h ein - Erstelle eine Variable des Typen ADXL345 mit geeigneter Bezeichnung

Aufgabe 4


4a | Code schreiben - Starte den Neigungssensor in der Setup Funktion - Speichere die Neigung-Werte in Variablen ab - Gib die Werte schön formatiert mit einem kleinen Delay auf dem seriellen Monitor wieder


4b | Teste aus, wie du den Neigungssensor Bewegen musst, um einen positiven und negativen Wert auf der X-Achse zu bekommen, ohne dass die anderen Werte sich verändern.

Autoren: Finn Dilan, Felix Neufeld, Jona Tregel Stand: 14.04.2023Seite 1 von 2

Infos für Lehrkräfte und Musterlösungen

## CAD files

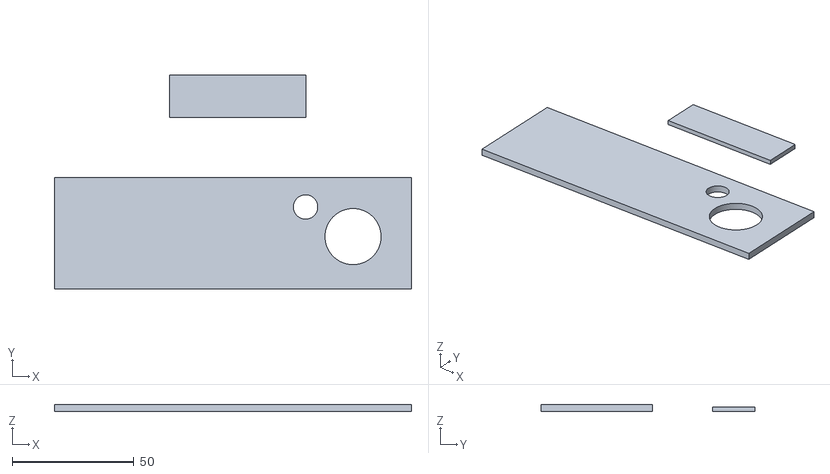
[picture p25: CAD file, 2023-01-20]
3D-Druck Dateien/Abdeckungen-Batterie-Controller-Final.stl
146.4 x 88.0 x 3.00

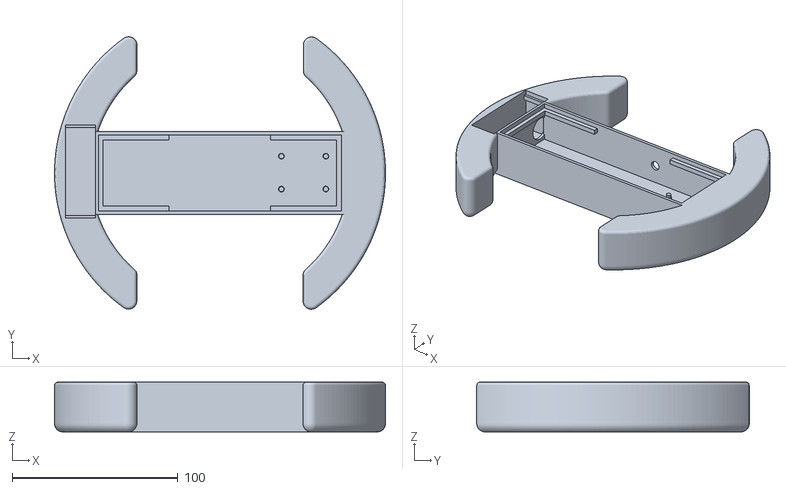
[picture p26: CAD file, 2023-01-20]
3D-Druck Dateien/Controller-Körper-Final.stl
199.4 x 164.2 x 30.0

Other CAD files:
3D-Druck Dateien/EingebtteteSysteme-Controller3dModell.f3z

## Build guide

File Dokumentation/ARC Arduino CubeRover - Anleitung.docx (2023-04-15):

# ACR – Arduino Cube Rover

Der Arduino Cube Rover ist zweiteiliges Arduino System, bei dem ihr selbst ein voll funktionsfähigen fahrenden Roboter zusammenbaut und programmiert, den ihr über einen selbstgebauten Controller mit Joystick und sogar Neigungssteuerung kontrollieren könnt.

## Material

- 2x Arduino Nano
- 1x H-Brücke (L298N)
- 2x 3-6V Getriebemotor mit Reifen
- 2x Bluetooth Modul (HC-05)
- 1x Joystick Modul (KY-023)
- 1x Neigungssensor (ADXL345)
- 3x verlötbarer Schalter
- 3x 9V Batterieblock
- 3x Breadboard (mittelgroß)
- 3x Breadboard (klein)
- 4x Morph3Dbot Würfel
- 1x Morph3Dbot Kugellager
- 2x Morph3Dbot Adapter für Batterieblöcke
- 2x Morph3Dbot Adapter für Breadboards
- 1x Morph3Dbot Adapter für H-Brücken
- 1x 3D gedruckte Controller Grundstruktur
  - Controller
  - Batteriefachdeckel
  - Elektronikfachdeckel

# Hardware aufbauen

Das Projekt besteht aus zwei verteilten eigenständigen Arduino Schaltungen: dem fahrenden Roboter selbst und dem Controller, der ihn steuert.

## Roboter

1. Gerüst bauen: Dazu nutzen wir die 4 Morph-3D-Bot Würfel und bringen sie mit den Verbindungsteilen in eine T-form, also drei in eine Reihe und eines seitlich an den mittleren Würfel. An den seitlich angebrachten Würfel kommt an die Unterseite das Kugellager, das später als Ausgleich zu den Motoren gilt.
2. Breadboard mit Arduino anbringen: Wir nehmen ein mittelgroßes Breadboard und kleben es auf den Morph3Dbot Breadboard-Adapter. Dann bringen wir den Adapter auf dem mittleren Würfel an und stecken dann den Arduino auf das Breadboard.
3. H-Brücke anbringen: Der Morph3Dbot Adapter für die H-Brücke besitzt 4 kleine Löcher an den Ecken. Wir befestigen die H-Brücke so auf dem Adapter, dass die Schraube von unten durch die Löcher nach oben zeigt, durch das jeweilige Loch an der H-Brücke rausguckt und dann mit einer Mutter festgezogen wird. Zwei Schrauben an gegenüberliegenden Ecken sollten ausreichen. Dann festigen wir den Adapter so oben auf dem außen liegenden Würfel, dass die Anschlüsse für den Arduino in Richtung des Arduinos zeigen.
4. Motoren anbringen: Bringe die zwei Morph3Dbot Adapter für Motoren an der Unterseite der beiden äußeren Würfel an. Danach montieren wir die Motoren so an dem Adapter, dass die Schrauben von dem Roboter wegzeigen und die Muttern außen zu sehen sind. Es ist darauf zu achten, dass die kleine Stange, auf die der Reifen gesteckt wird, auf der Außenseite ist und der Gewichtsverlagerung wegen die Motoren so anbringen, dass die Kabelanschlüsse auf der Seite des Kugellagers sind.
5. Bluetooth-Modul anbringen: Die Prozedur mit dem mittelgroßen Breadboard mit Adapter ist die gleiche wie in Schritt 2. Nun stecken wir das Bluetooth-Modul in das Breadboard.
6. Batterien anbringen: Die Morph3Dbot Adapter für die Batterien kommen jeweils links und rechts neben den einen einzelnen mittigen Würfel, das hilft noch etwas bei der Verlagerung des Gewichts.
7. Verkabelung: Nun müssen alle angebrachten Bauteile miteinander verkabelt werden. Wie die einzelnen Bauteile verkabelt werden, wisst ihr ja schon.

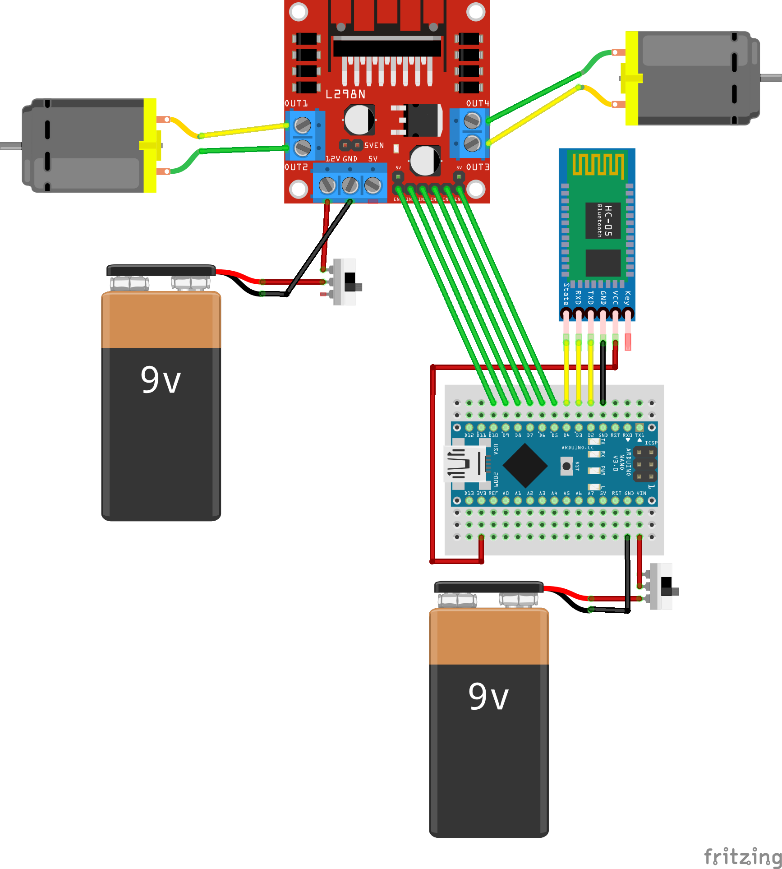
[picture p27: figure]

## Controller

1. 3D-Druck des Gehäuses: Bei diesem Schritt hängt es davon ab, ob ihr das Gehäuse bereits fertig gedruckt besitzt oder ihr es noch drucken musst. Wenn das Gehäuse noch gedruckt werden muss, könnt ihr gerne der vorgegebenen Gehäuse-Datei kleine Änderungen durchführen, die es für euch schöner oder angenehmer machen. Wenn ihr gut mit Fusion360 umgehen könnt, sind auch Extras wie Einlass-Fassungen für die Bauteile oder effiziente Klicksysteme für die Verschlüsse eine gute Erweiterung.
2. Arduino anbringen: Wie auch bei dem Roboter bringen wir den Arduino Nano auf einem mittelgroßen Breadboard an. Das Breadboard mit dem Arduino Nano drauf legen wir dann nun einfach in das Gehäuse.
3. Joystick anbringen: Das Joystickmodul wird einfach auf die vier im Gehäuse hochstehenden Säulen gelegt.
4. Neigungssensor anbringen: Der Neigungssensor wird auf zwei kleine Breadboards angebracht. Dabei ist es wichtig, dass jeweils auf beiden Seiten die Breadboards zwei Reihen übrighaben. Das garantiert, dass die Breadboard-Anordnung in das Gehäuse passt, aber noch genug Platz für Anschlüsse sind. Den Neigungssensor legen wir dann nun hochkant in das Gehäuse direkt neben das Batteriefach.
5. Bluetooth-Modul anbringen: Das Bluetooth-Modul wird ebenfalls auf einem kleinen Breadboard angebracht, dabei muss das Modul in die äußerste Reihe gesteckt werden, denn da das Modul vertikal in dem Breadboard steckt, muss das Breadboard um 90 Grad gedreht in das Gehäuse gelegt werden, so, dass die Löcher vom Breadboard in Richtung Batterie schauen.
6. Stromversorgung: Das Batteriefach besitzt ein kleines Loch, durch welches die Kabel vom Batterie-Kabelaufsatz in das Innere des Gehäuse geführt werden. Im Dach des Gehäuses gibt es ein kleines Loch, in das der Schalter gesteckt und fixiert wird.
7. Verkabelung: Wie auch beim Roboter müssen nun alle angebrachten Bauteile miteinander verkabelt werden. Auch wie diese Bauteile verkabelt werden, solltet ihr bereits wissen.

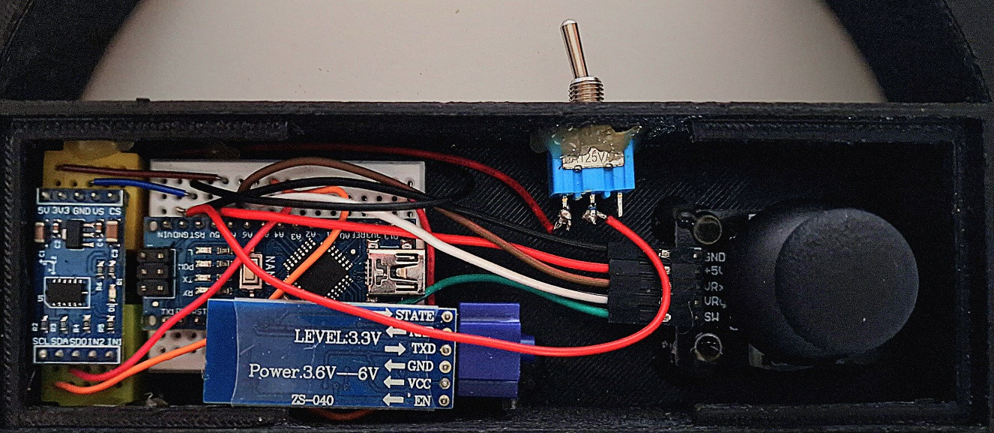
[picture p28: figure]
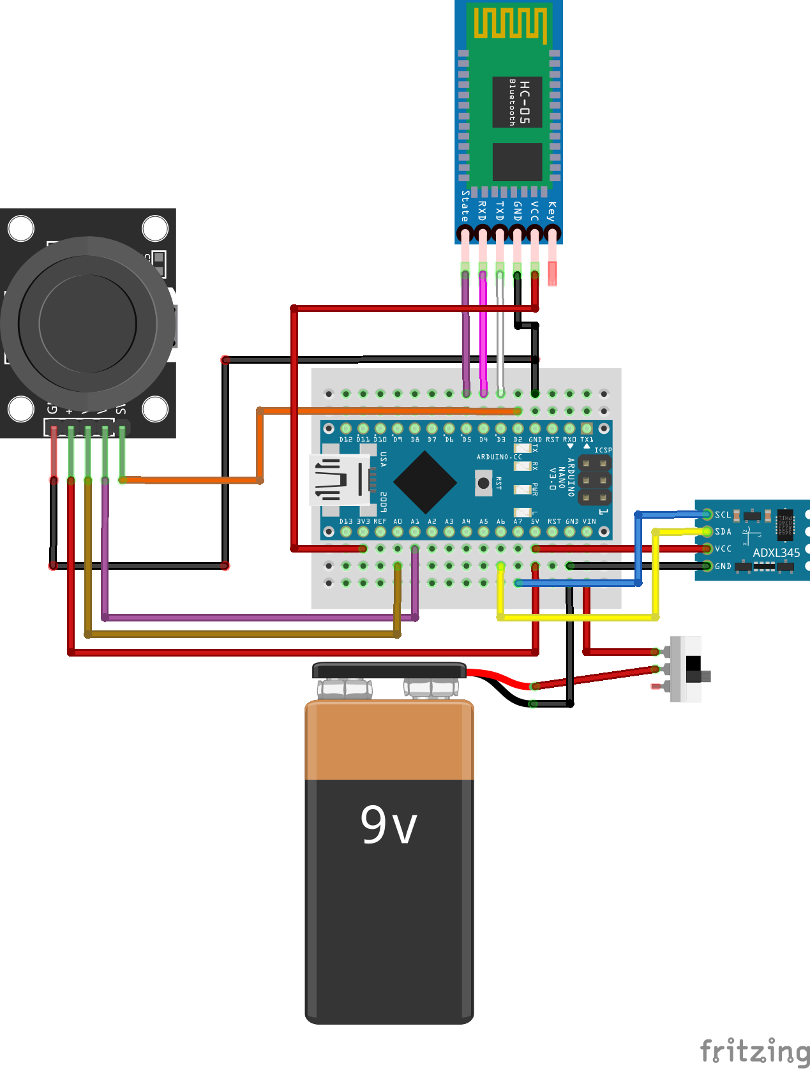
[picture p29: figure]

# Programmierung

Da wir zwei verschiedene Arduino Schaltungen haben, die auch beide vollkommen andere Aufgaben übernehmen, brauche wir natürlich auch zwei unterschiedliche Arduino Skripts. Diesmal beginnen wir mit dem Controller, da dieser in dieser Struktur die Rolle des Masters einnimmt.

## Controller

1. Setup: Der Taster des Joysticks muss als Eingang definiert werden. Darüber hinaus muss die serielle Kommunikation und virtuelle Bluetooth serielle Kommunikation mit 38400er Rate gestartet werden. Als letztes muss noch der Neigungssensor eingeschaltet werden.
2. Bereits fertiger Code: Für die Umrechnung der Joystick Daten in nutzbare Motor Daten ist eine komplizierte mathematische Berechnung von Nöten, die in diesem Fall jegliche Rahmen sprengen würde, daher wird sie von eurem Lehrer vorgegeben. Es müssen insgesamt fünf Funktionen sein: bool yAchsePos(), bool yAchseNeg(), bool xAchsePos(), bool xAchseNeg() und void calculateSpeed().
3. Bluetooth-Verbindung: Es muss eine Funktion geschrieben werden, die testet, ob die Bluetooth-Verbindung noch besteht. Die Funktion bekommt nichts übergeben und gibt ein bool zurück. In einer while-schleife wird nun der State-Pin nach HIGH abgefragt und bei Eintreten wird die while-condition Variable auf false gesetzt (je nachdem wie ihr sie definiert habt auch andersherum) und es wird noch in der while-schleife der bool true zurückgegeben. Bei der nächsten Abfrage wird die while schleife also direkt übersprungen. Damit es aber bei Abbruch der Verbindung nicht zu Fehlern kommt und die while-condition wieder korrekt ist, müssen wir nach die while-Schleife noch eine Abfrage des State-Pin nach LOW einbauen, die bei Eintreten die while-condition Variable wieder auf true setzt und false returned.
4. Daten übertragen: Die Datenübertragen lagern wir auch in eine Funktion aus. In dieser Funktion müssen wir das Konzept überlegen, wonach die Datenübertragen funktionieren soll. Eine Möglichkeit ist ein Array mit vier Elementen: zwei für die Richtung und zwei für die Geschwindigkeit. Die Richtung wird als -1 für Rückwärts, 0 für Stillstand und 1 für Vorwärts definiert und für die Übertragung jeweils eins ins positive geshiftet, da Bluetooth nur positive Werte übertragen kann. Die Geschwindigkeit ist das Ergebnis der calculateSpeed() Funktion, bei der die Variable motLInt die Geschwindigkeit des linken Motors und motRInt die Geschwindigkeit des rechten Motors ist. Die Richtung kann auch aus dem Vorzeichen der Variablen ausgelesen werden. Es ist auch zu empfehlen, um den 0 Punkt herum einen gewissen Bereich als Dead-Space zu definieren (+-32 oder +-64 sind Standardwerte), bei der auch noch weiterhin 0 als Geschwindigkeit übertragen wird, da sonst ein Stillstand so gut wie unmöglich ist. Am Ende der Funktion, nachdem das Array vollständig und nach einem gewissen Konzept vorbereitet wurde, kann dies nun über die virtuelle serielle Kommunikation übertragen werden.
5. Steuerungsart wechseln: Da die Steuerung des Roboters auf zwei verschiedene Arten geschehen soll, müssen wir eine Funktion schreiben, die aktuell geltende Steuerungsart bestimmt. Der Wechsel der Steuerung soll über den Taster des Joysticks gewechselt werden. Wie man Modi anlegt und mit Hilfe des Tasters wechselt ist ja bereits bekannt.
6. Daten auslesen: Hier müssen die Daten ausgelesen werden. Dazu sollte erstmal bekannt sein, welche Steuerungsart genutzt wird, daher zuerst einmal die Steuerungswechsel Funktion aufrufen. Die y-Achse wird immer über den Joystick ausgelesen, das kann also außerhalb einer Abfrage passieren. Die x-Achse wird jetzt je nach aktuelle Steuerungsart über Joystick oder Neigungssensor ausgelesen. Achtet darauf, dass der Sensor manchmal in der Ausgangsstellung, in der 0 ausgegeben werden sollte einen etwas größeren oder kleinen Wert haben kann, dann müsst ihr diese mit Code ausgleichen. Da wir für die calculateSpeed() Funktion ein Wertebereich von 0 bis 1023 benötigen, aber der Neigungssensor einen Bereich von -256 bis 255 hat, müssen wir diesen erst noch mappen und mit einer int() funktion umgeben, da der Rückgabewert ein long ist.
7. Loop: In der Loop müssen wir nun nur noch einmal abfragen, ob die Bluetooth-Verbindung besteht. Wenn ja, dann können wir nacheinander die Daten lesen Funktion, die calculateSpeed() Funktion und Daten übertragen Funktion aufrufen.

## Roboter

1. Setup: Die Anschlüsse der H-Brücke müssen als Ausgänge definiert werden. Darüber hinaus muss die serielle Kommunikation und virtuelle Bluetooth serielle Kommunikation mit 38400er Rate gestartet werden.
2. Motoren Richtungsfunktionen: Es müssen die Funktionen angelegt werden, die mit Angabe der Richtung automatisch die Motoren so ansteuern, dass diese sich in die gewünschte Richtung drehen.
3. Bluetooth-Verbindung: Auch bei dem Roboter muss eine Funktion geschrieben werden, die die Bluetooth-Verbindung testet und es kann im Grunde die Funktion des Controllers eins zu eins übernommen werden. Dabei ist es wichtig, dass zusätzlich noch bei der Abfrage, ob die Verbindung abgebrochen ist, die Geschwindigkeit und Richtung der Motoren auf Stillstand gesetzt werden.
4. Loop: Das ist der einfachste Teil. Hier muss lediglich die Bluetooth-Verbindung Funktion und das Ankommen von Bluetooth-Daten abgefragt werden. Falls sowohl eine Verbindung besteht als auch Bluetooth-Daten zum Lesen vorhanden sind können die Daten in einen vorbereiteten Buffer geschrieben werden. Hier ist darauf zu achten, dass das Auslesen des Buffers nach dem gleichen Konzept funktioniert, das wir vorher in dem Sketch des Controllers definiert haben. Dann müssen wir nur noch die Daten, die wir übertragen haben an die Motor Richtungsfunktionen übergeben bzw. mit analogWrite() die Geschwindigkeit vorgeben.

Autoren: Finn Dilan, Felix Neufeld, Jona Tregel Stand: 15.04.2023Seite 1 von 3

Anleitung zur Durchführung des ACR-Projekts

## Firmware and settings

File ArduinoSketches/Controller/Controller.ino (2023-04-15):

#include <ADXL345.h>
#include <Wire.h>
#include <SoftwareSerial.h>

//Generelles
int junk;
int motRInt;
int motLInt;
uint8_t buf[4];
enum controlStyle {JOYSTICK, TILT_SENSOR};
controlStyle currentStyle = JOYSTICK;
ADXL345 adxl;

//Bluetooth Kommunikation
SoftwareSerial btSerial(5,4);
bool BTconnected;
const byte BTpin = 3;

//Speed Calculation
int xAchse;
int yAchse;
float Speed;
float Fix = 512;
float haelfte = 512;
float alpha;
float motR = 0;
float motL = 0;
int marche = 64;

//Joystick
const int SW = 2;
const int VRx = 7;
const int VRy = 6;
bool buttonPressed;

void setup() {
  pinMode(SW, INPUT_PULLUP);
  btSerial.begin(38400);
  Serial.begin(38400);
  adxl.powerOn();
}

bool yAchsePos() {
  if (yAchse > Fix + marche) return true;
  else return false;
}

bool yAchseNeg() {
  if (yAchse < Fix - marche) return true;
  else return false;
}

bool xAchsePos() {
  if (xAchse > Fix + marche) return true;
  else return false;
}

bool xAchseNeg() {
  if (xAchse < Fix - marche) return true;
  else return false;
}

void calculateSpeed() {
  Speed = sqrt(sq(xAchse - haelfte) + sq(yAchse - haelfte));
  if (yAchsePos()) {
    if (xAchsePos()) {
      motR = -1;
      alpha = degrees(asin(map(yAchse, haelfte, 1023, 0, 1)));
      motL = map(alpha, 0, 90, 1, -1);
    }
    else if(xAchseNeg()) {
      motL = -1;
      alpha = degrees(asin(map(yAchse, haelfte, 1023, 0, 1)));
      motR = map(alpha, 0, 90, 1, -1);
    }
    else {
      motR = -1;
      motL = -1;
      Speed = yAchse-haelfte;
    }
  }
  else if (yAchseNeg()) {
    if (xAchsePos()) {
      motL = 1;
      alpha = degrees(asin(map(yAchse, haelfte, 0, 0, 1)));
      motR = map(alpha, 0, 90, -1, 1);
    }
    else if (xAchseNeg()) {
      motR = 1;
      alpha = degrees(asin(map(yAchse, haelfte, 0, 0, 1)));
      motL = map(alpha, 0, 90, -1, 1);
    }
    else {
      motR = 1;
      motL = 1;
      Speed = sqrt(sq(yAchse - haelfte));
    }
  }
  else {
    if (xAchsePos()) {
      motL = 1;
      motR = -1;
      Speed = xAchse - haelfte;
    }
    else if (xAchseNeg()) {
      motL = -1;
      motR = 1;
      Speed = sqrt(sq(xAchse - haelfte));
    }
    else {
      motL = 0;
      motR = 0;
      Speed = 0;
    }
  }
  if (Speed > 512) Speed = 512;
  motR *= Speed;
  motL *= Speed;
  motLInt = int(map(motL, -512, 512, -255, 255));
  motRInt = int(map(motR, -512, 512, -255, 255));
}

bool connectionCheck(){
  while(!BTconnected)
    {
      if (digitalRead(BTpin)==HIGH){
        BTconnected = true;
        return true;
      } 
      else{
        return false;
      }   
  if(digitalRead(BTpin)==LOW){
    BTconnected = false;
    return false;
  }
  return true;
  }
}

void bluetoothTransmission(){
  if(motLInt < -64) {
    buf[0] = 0;
    buf[1] = static_cast<uint8_t>(-motLInt);
  } else if (motLInt > 64) {
    buf[0] = 2;
    buf[1] = static_cast<uint8_t>(motLInt);
  } else {
    buf[0] = 1;
    buf[1] = 0;
  }

  if(motRInt < -64) {
    buf[2] = 0;
    buf[3] = static_cast<uint8_t>(-motRInt);
  } else if(motRInt > 64) {
    buf[2] = 2;
    buf[3] = static_cast<uint8_t>(motRInt);
  } else {
    buf[2] = 1;
    buf[3] = 0;
  }
  btSerial.write(buf, 4);
}

void buttonSwitch() {
  if(buttonPressed && digitalRead(SW) == LOW) {
    if(currentStyle == JOYSTICK) {
      currentStyle = TILT_SENSOR;
    } else {
      currentStyle = JOYSTICK;
    }
    buttonPressed = false;
  }
  buttonPressed = digitalRead(SW);
}

void readData() {
  buttonSwitch();
  if(currentStyle == JOYSTICK) {
      xAchse = analogRead(VRx);
    } else {
      adxl.readXYZ(&xAchse, &junk, &junk);
      xAchse = int(map(xAchse, -256, 255, 0, 1023));
    }
    yAchse = analogRead(VRy);

    if (xAchse < 576 && xAchse > 448) xAchse = 512;
    if (yAchse < 576 && yAchse > 448) yAchse = 512;
    if (yAchse > 900) xAchse = 512;
    if (yAchse < 128) xAchse = 512;
}

void loop() {  
  if(connectionCheck()){
    readData();
    calculateSpeed();
    bluetoothTransmission();
  }
  delay(100);
}

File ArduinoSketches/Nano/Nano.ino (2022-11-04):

// Gleichstrommotor 1

int GSM1 = 6;
int in1 = 7;
int in2 = 8;

// Gleichstrommotor 2

int GSM2 = 11;
int in3 = 9;
int in4 = 10;

// Bluetooth Daten
char xSign;
signed char xValue;
char ySign;
signed char yValue;

void setup()
{
  pinMode(GSM1, OUTPUT);    
  pinMode(GSM2, OUTPUT);
  pinMode(in1, OUTPUT);
  pinMode(in2, OUTPUT);
  pinMode(in3, OUTPUT);
  pinMode(in4, OUTPUT);
  //serieller Monitor wird gestartet, Baudrate auf 9600 festgelegt
  Serial.begin(9600);  
}
void loop()
{
  digitalWrite(in1, HIGH);  // Motor 1 beginnt zu rotieren
  digitalWrite(in2, LOW);

enum Rotation {
  forwards, 
  backwards, 
  stopped};
}

void engine1(Rotation rot) {
  if(rot == forwards) {
    digitalWrite(in1, HIGH);  // Motor 1 beginnt zu rotieren
    digitalWrite(in2, LOW);
  } else if(rot == backwards) {
    digitalWrite(in1, LOW);  // Motor 1 beginnt rückwärts zu rotieren
    digitalWrite(in2, HIGH);
  } else {
    digitalWrite(in1, LOW);  // Motor 1 stoppt
    digitalWrite(in2, LOW);
  }
}

void engine2(Rotation rot) {
  if(rot == forwards) {
    digitalWrite(in3, HIGH);  // Motor 2 beginnt zu rotieren
    digitalWrite(in4, LOW);
  } else if(rot == backwards) {
    digitalWrite(in3, LOW);  // Motor 2 beginnt zu rückwärts rotieren
    digitalWrite(in4, HIGH);
  } else {
    digitalWrite(in3, LOW);  // Motor 2 stoppt
    digitalWrite(in4, LOW);
  }
}



void loop()
{
  if(Serial.available()) //wenn Daten empfangen werden...      
{
   xSign=Serial.read();     //0 für keine Bewegung, 1 für positive Zahlen (vorwärts fahren), -1 für negative Zahlen (rückwärts fahren)
   xValue=Serial.read();    //Werte zwischen 0 und 255 für die Geschwindigkeit
   ySign=Serial.read();
   yValue=Serial.read();

   if(ySign == 1) {//Fall 1: Motor 1 & 2 nach vorne
     engine1(Rotation.forwards);
     engine2(Rotation.forwards);
   } else if(ySign == -1) {
     //Fall 2: Motor 1 & 2 nach hinten
     engine1(Rotation.backwards):
     engine2(Rotation.backwards);
   } else if(ySign == 0 && xSign == 1) {
     //Fall 3: Motor 1 dreht sich nach vorne, Motor 2 dreht sich nach hinten
     engine1(Rotation.forwards);
     engine2(Rotation.backwards);
   } else if(ySign == 0 && xSign == -1) {
     //Fall 4: Motor 1 dreht sich nach hinten, Motor 2 dreht sich nach vorne
     engine1(Rotation.backwards);
     engine2(Rotation.forwards);
   } else {
     //Fall 5: Motor 1 & 2 sind aus
     engine1(Rotation.stopped);
     engine2(Rotation.stopped);
   }
   analogWrite(GSM1, 0);
   analogWrite(GSM2, 0);
}

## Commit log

2022-11-03 Arduino Sketche erstellt
2022-11-05 Sketch Umbennenung und kleinere Fixes
    [Robot.ino]
2022-11-06 Bluetooth Connection und Joystick Input Calculation
2023-01-20 Add files via upload
    The 3D-Models to put into a 3D-Printer specific Software
    [Abdeckungen-Batterie-Controller-Final.stl, Controller-Körper-Final.stl]
2023-01-20 Ordner Strukturierung
    [Abdeckungen-Batterie-Controller-Final.stl, Controller-Körper-Final.stl]
2023-04-15 Debug entfernt und bisschen schöner gemacht
